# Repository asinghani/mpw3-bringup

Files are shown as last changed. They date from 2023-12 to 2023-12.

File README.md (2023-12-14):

# MPW3 Bringup / Characterization

Experiments in bringing up SKY130 MPW-3 chips from the initial tapeout in November 2021. Similarly to [MPW-1](https://github.com/asinghani/mpw1-bringup), the standardized "Caravel" padframe used in this tapeout had hold-time violations between 

## Breakout PCBs

- Characterization PCB [Schematic](boards/mpw3-common/schematic.pdf)
    - Independent voltage regulators for padframe and core (with non-volatile memory)
    - DS1077LU-50 clock generator with 50kHz - 50MHz output frequency + non-volatile memory
    - MCP23017 GPIO expanders for scanning chip I/Os
    - MCP1319 reset supervisor
    - MicroMod-style socket for Caravel chip breakout

- FTDI Breakout [Schematic](boards/uart-breakout/schematic.pdf)
    - Connects characterization PCB to FT232RL for UART access over USB
    - Includes LEDs, switches, and SPI FRAM for use with picoRF0 CPU

- VGA Breakout [Schematic](boards/vga-breakout/schematic.pdf)
    - Breaks out infinite-runner game and pong game to a 2-bit VGA DAC
    - Includes buffer chips for 

## Repo Structure

- `boards/` - KiCAD design files for breakout PCBs
- `parts/` - I/O characterization results for several dies
- `scripts/i2c_iface.py` - Script for interfacing with the voltage regulators, clock generator, and GPIO expanders on the characterization board
- `programs/` - Programs for running on the Caravel processor for the different applications
    - `aes_test.c` - Test the AES core on crypto-accelerator-chip-v2 design
    - `gpio_config_io_dino.py` - GPIO configuration for the VGA runner game
    - `gpio_config_io_pong.py` - GPIO configuration for the VGA pong game
    - `picorf0_test.c` - Test program for the picoRF0 custom CPU core
    - `read_ident.c` - Reads the ROM identifier and build number in the SHA and AES cores
    - `sha256_test.c` - Test the SHA256 core with some test vectors
    - `spi_fram.c` - Test program for using the Caravel SPI master to interface with an FRAM chip
    - `uart_working.c` - Workaround for UART RX on MPW-3 Caravel

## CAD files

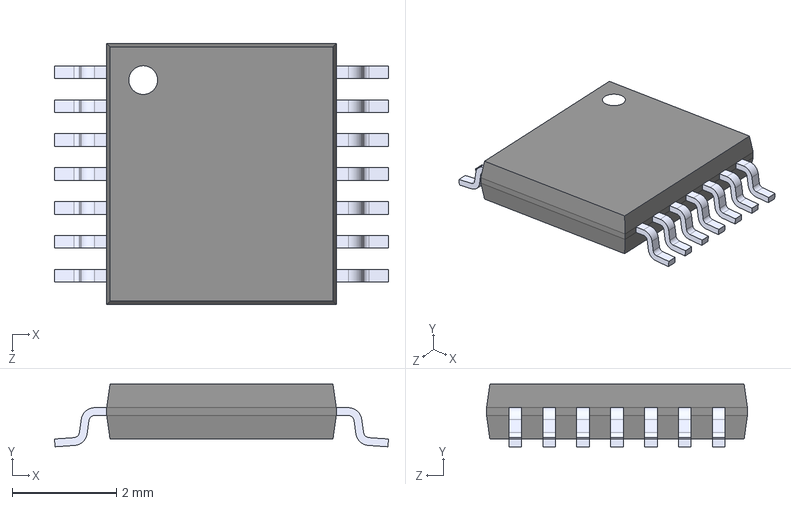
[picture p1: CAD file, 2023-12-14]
boards/mpw3-common/parts/TPL0102/TPL0102-100QPWREP.step
6.40 x 1.20 x 5.00 mm

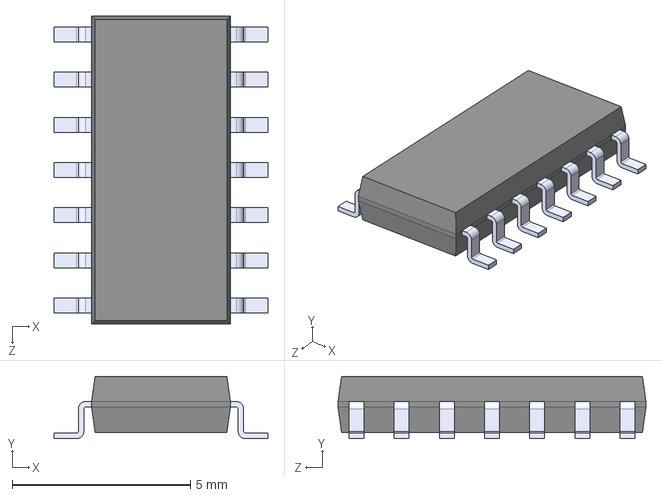
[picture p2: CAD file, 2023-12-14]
boards/uart-breakout/parts/SN74LVC32ADR/SN74LVC32ADR.step
6.00 x 1.75 x 8.65 mm

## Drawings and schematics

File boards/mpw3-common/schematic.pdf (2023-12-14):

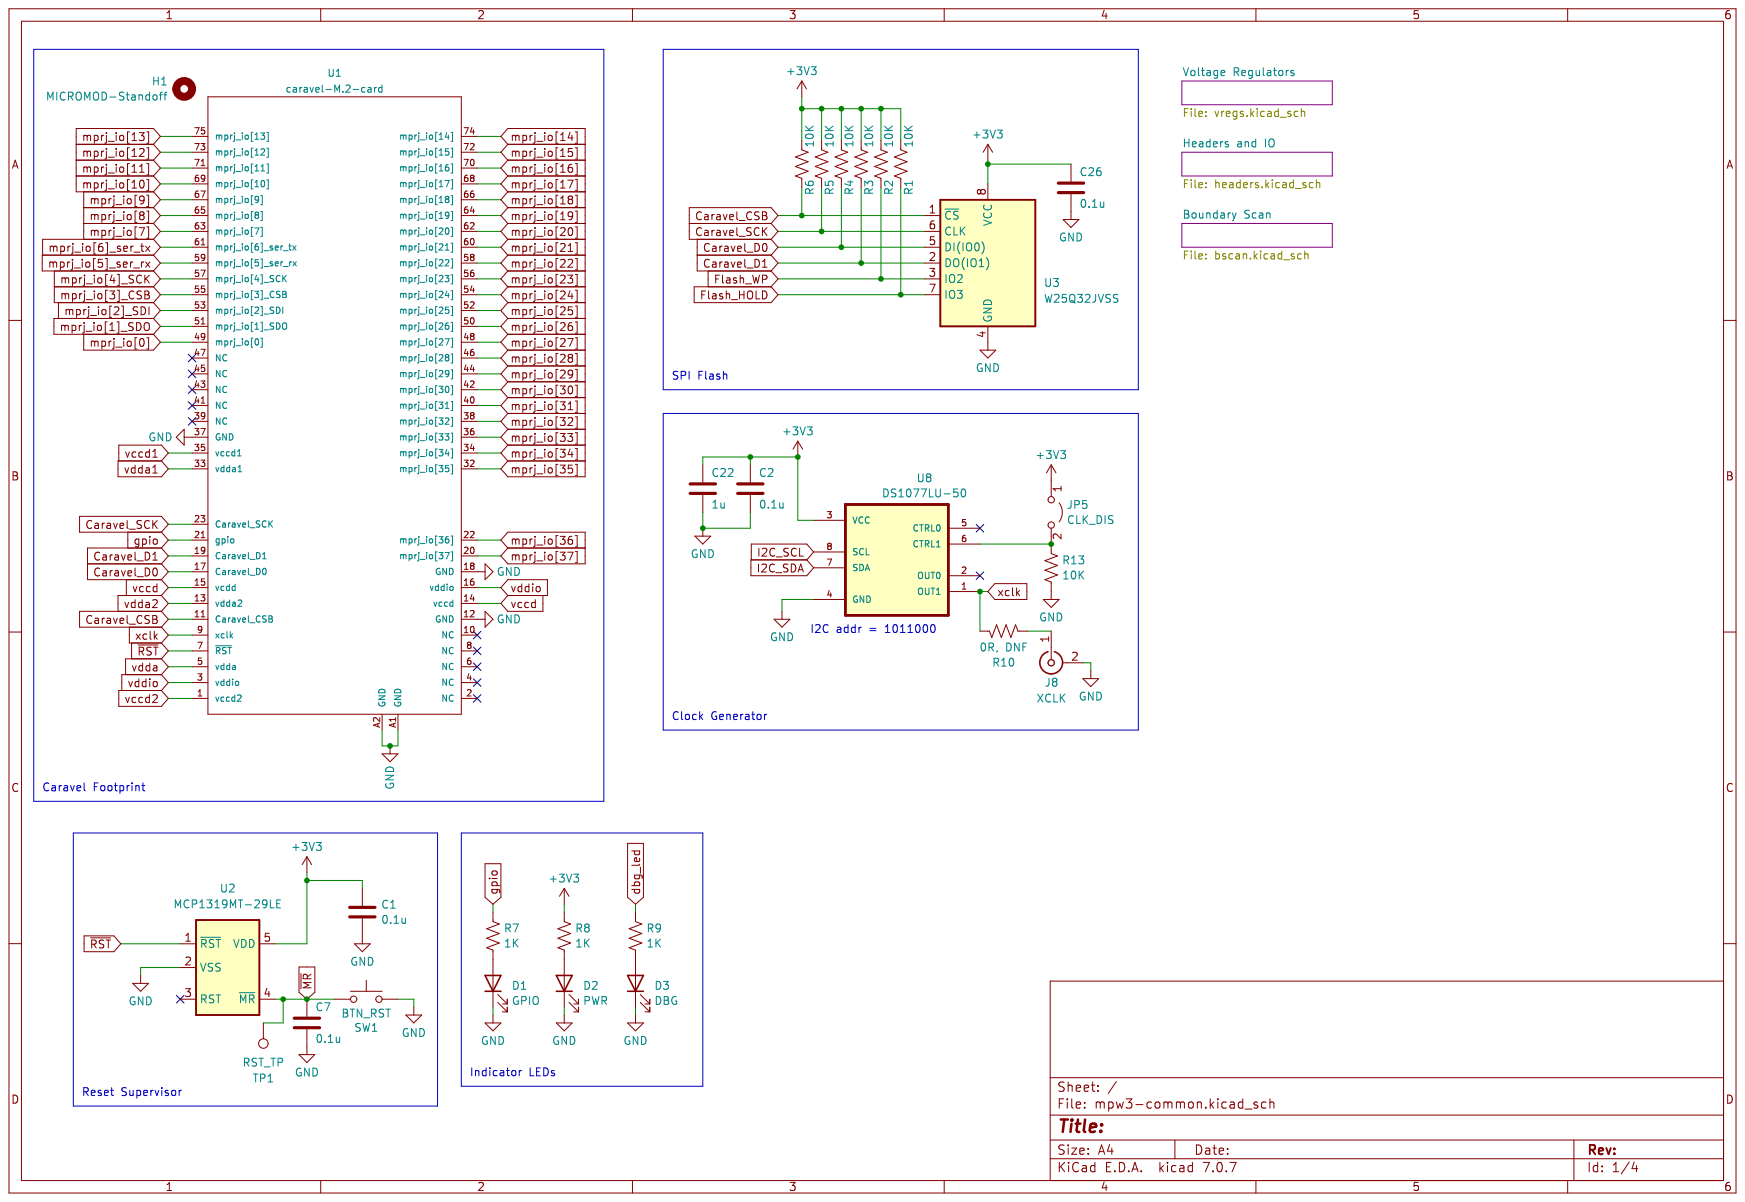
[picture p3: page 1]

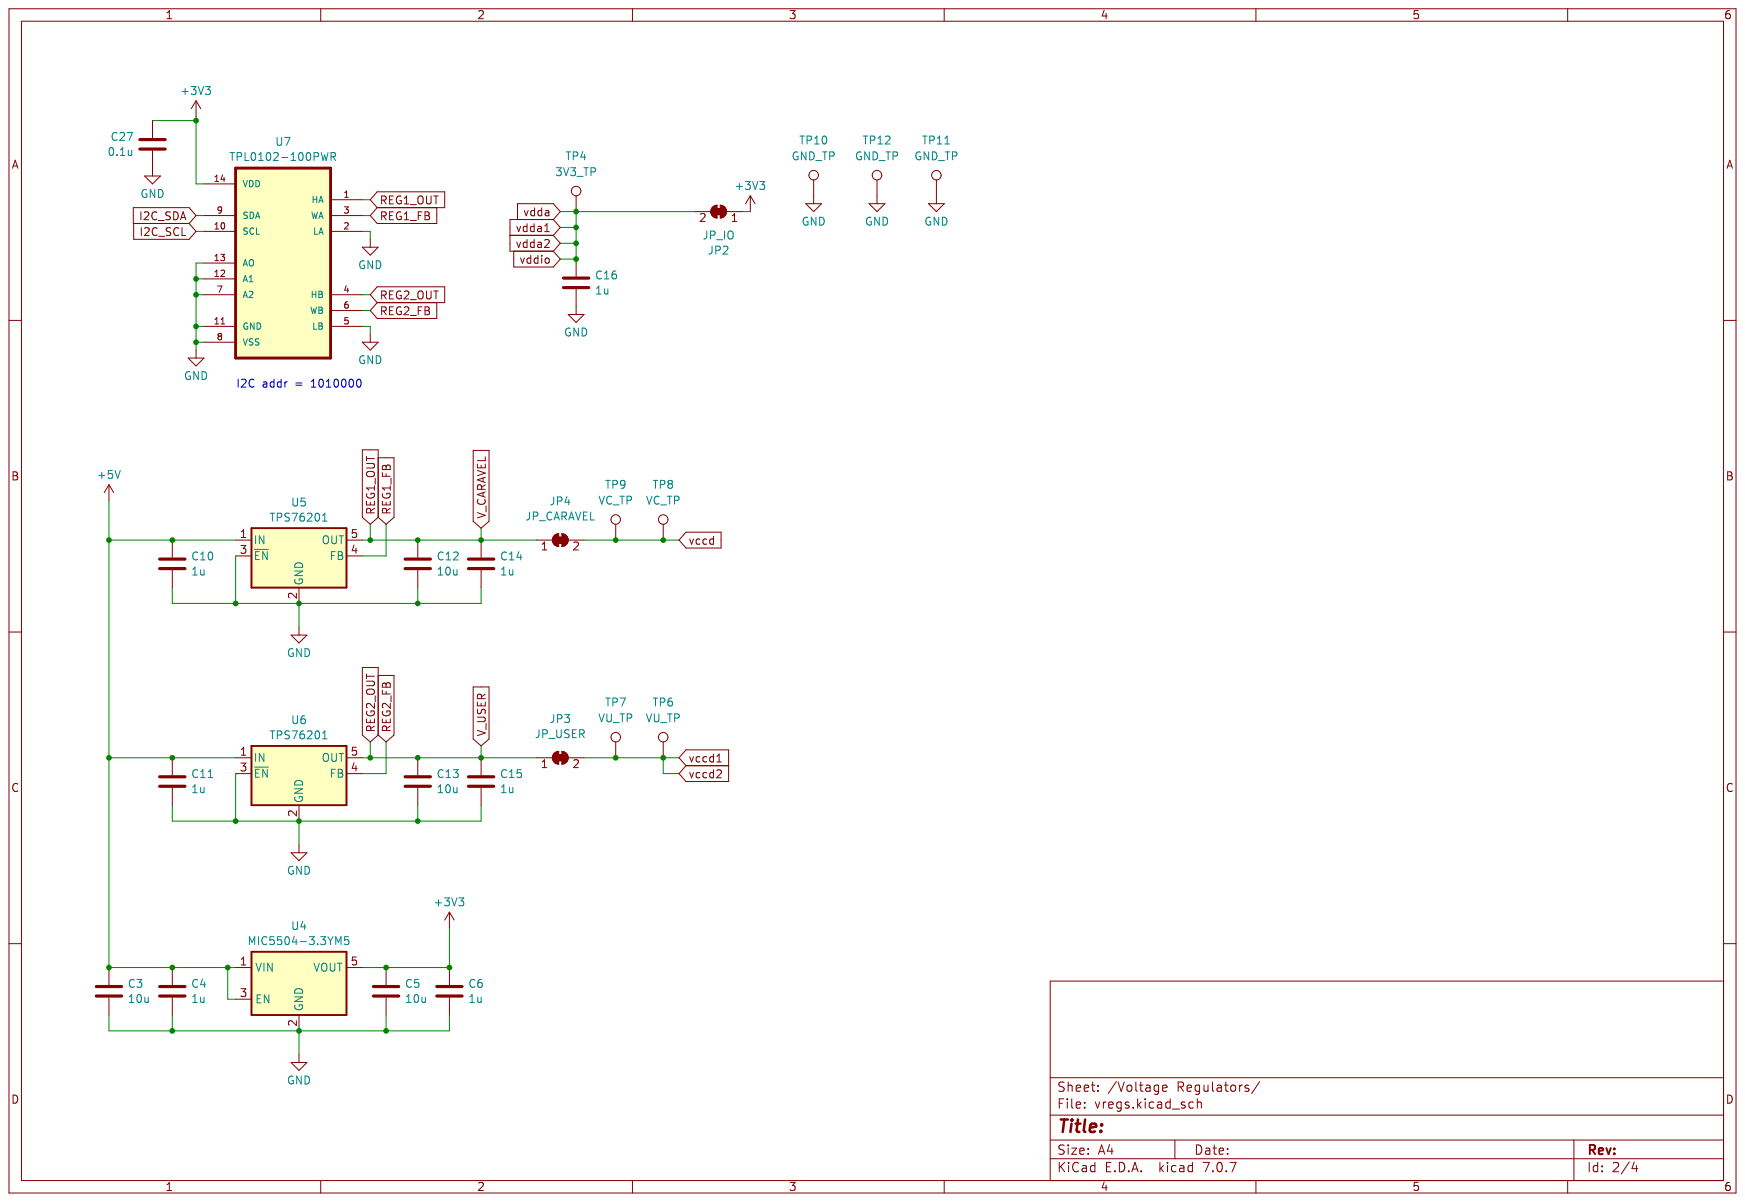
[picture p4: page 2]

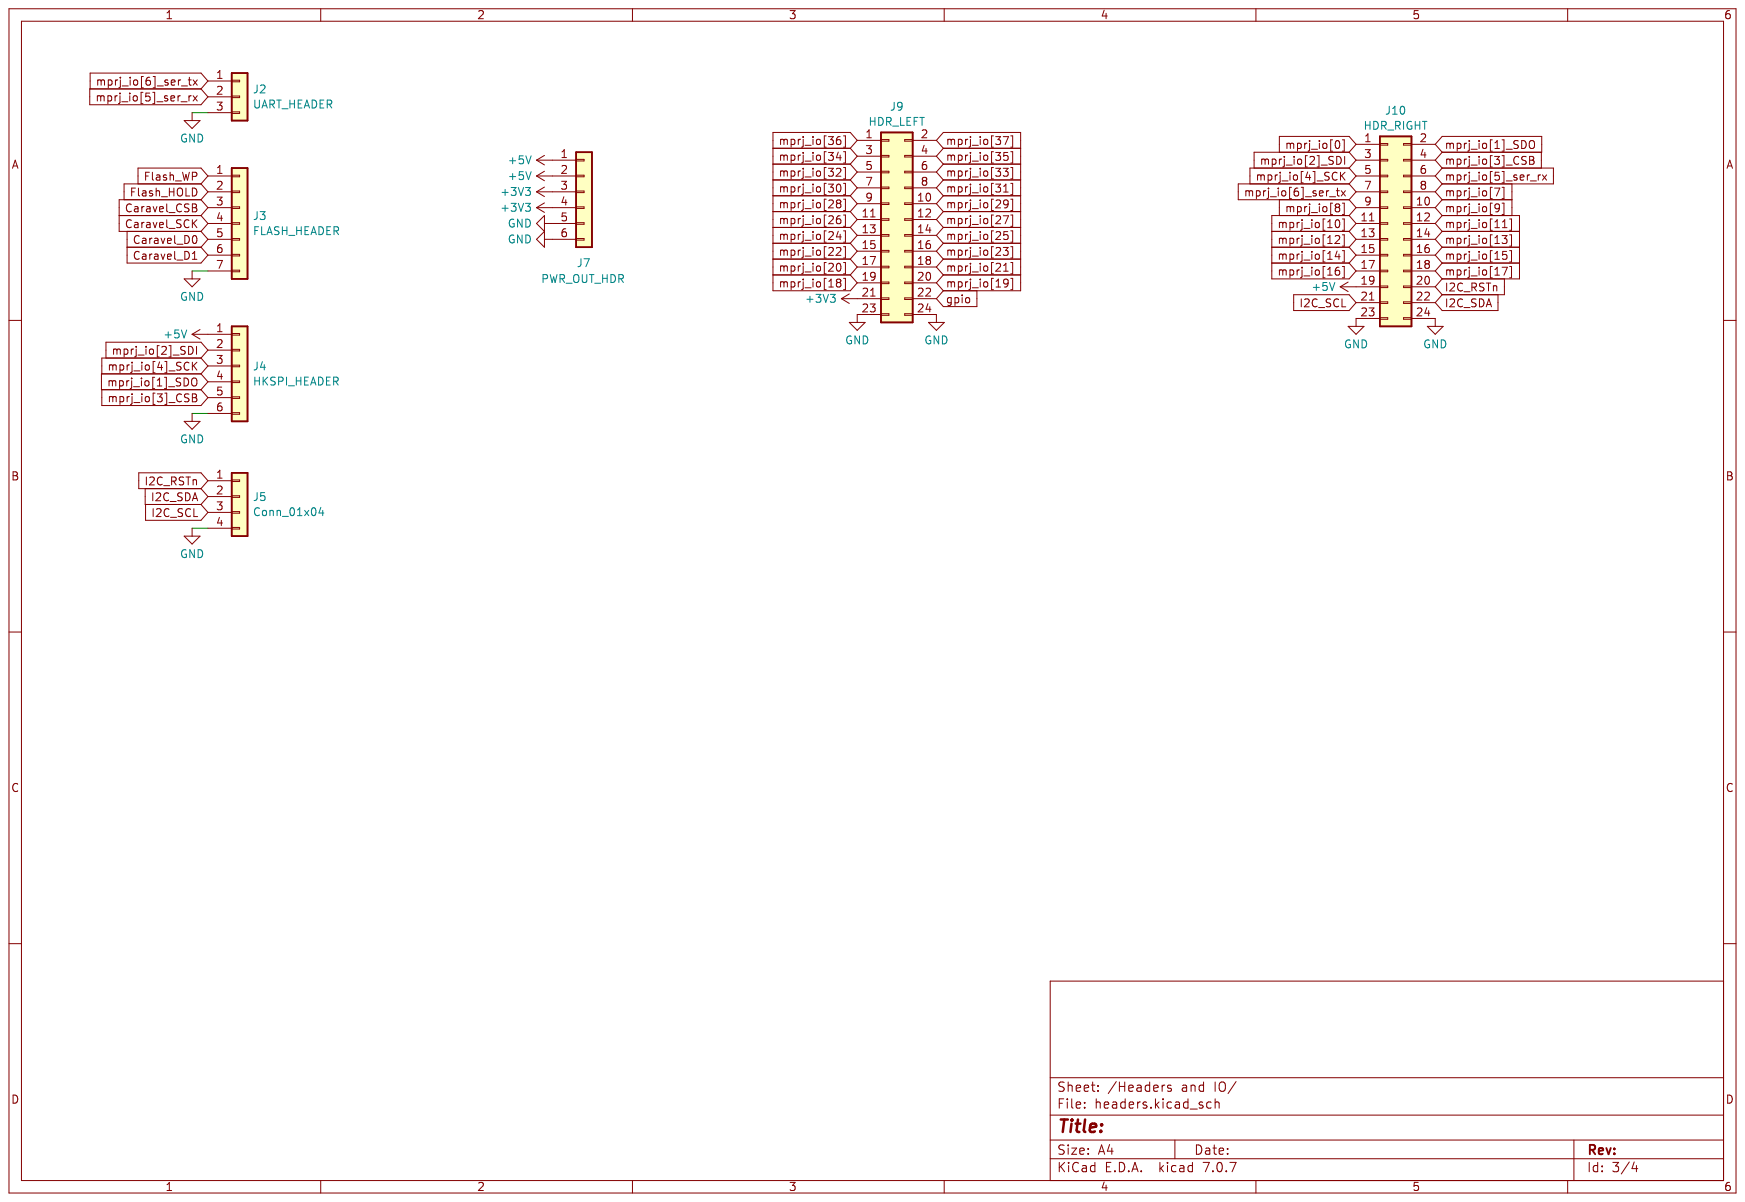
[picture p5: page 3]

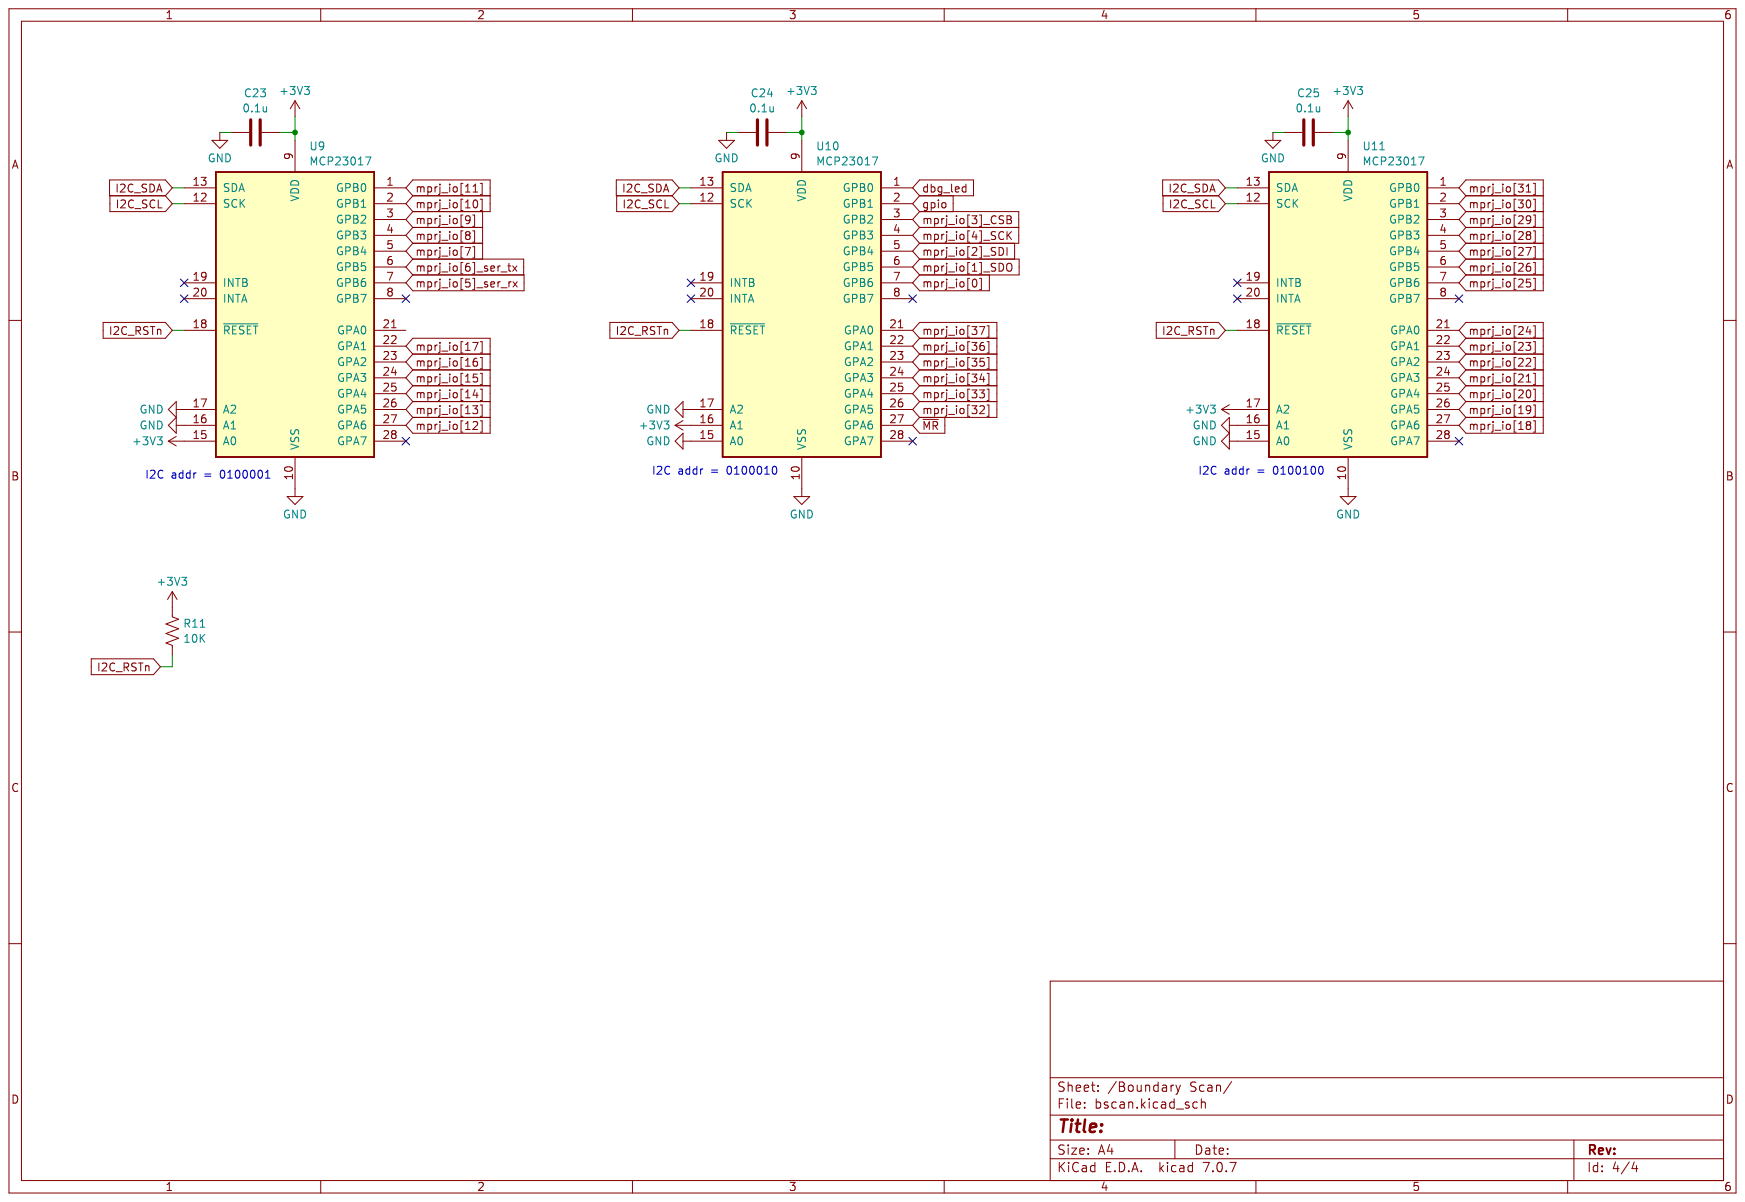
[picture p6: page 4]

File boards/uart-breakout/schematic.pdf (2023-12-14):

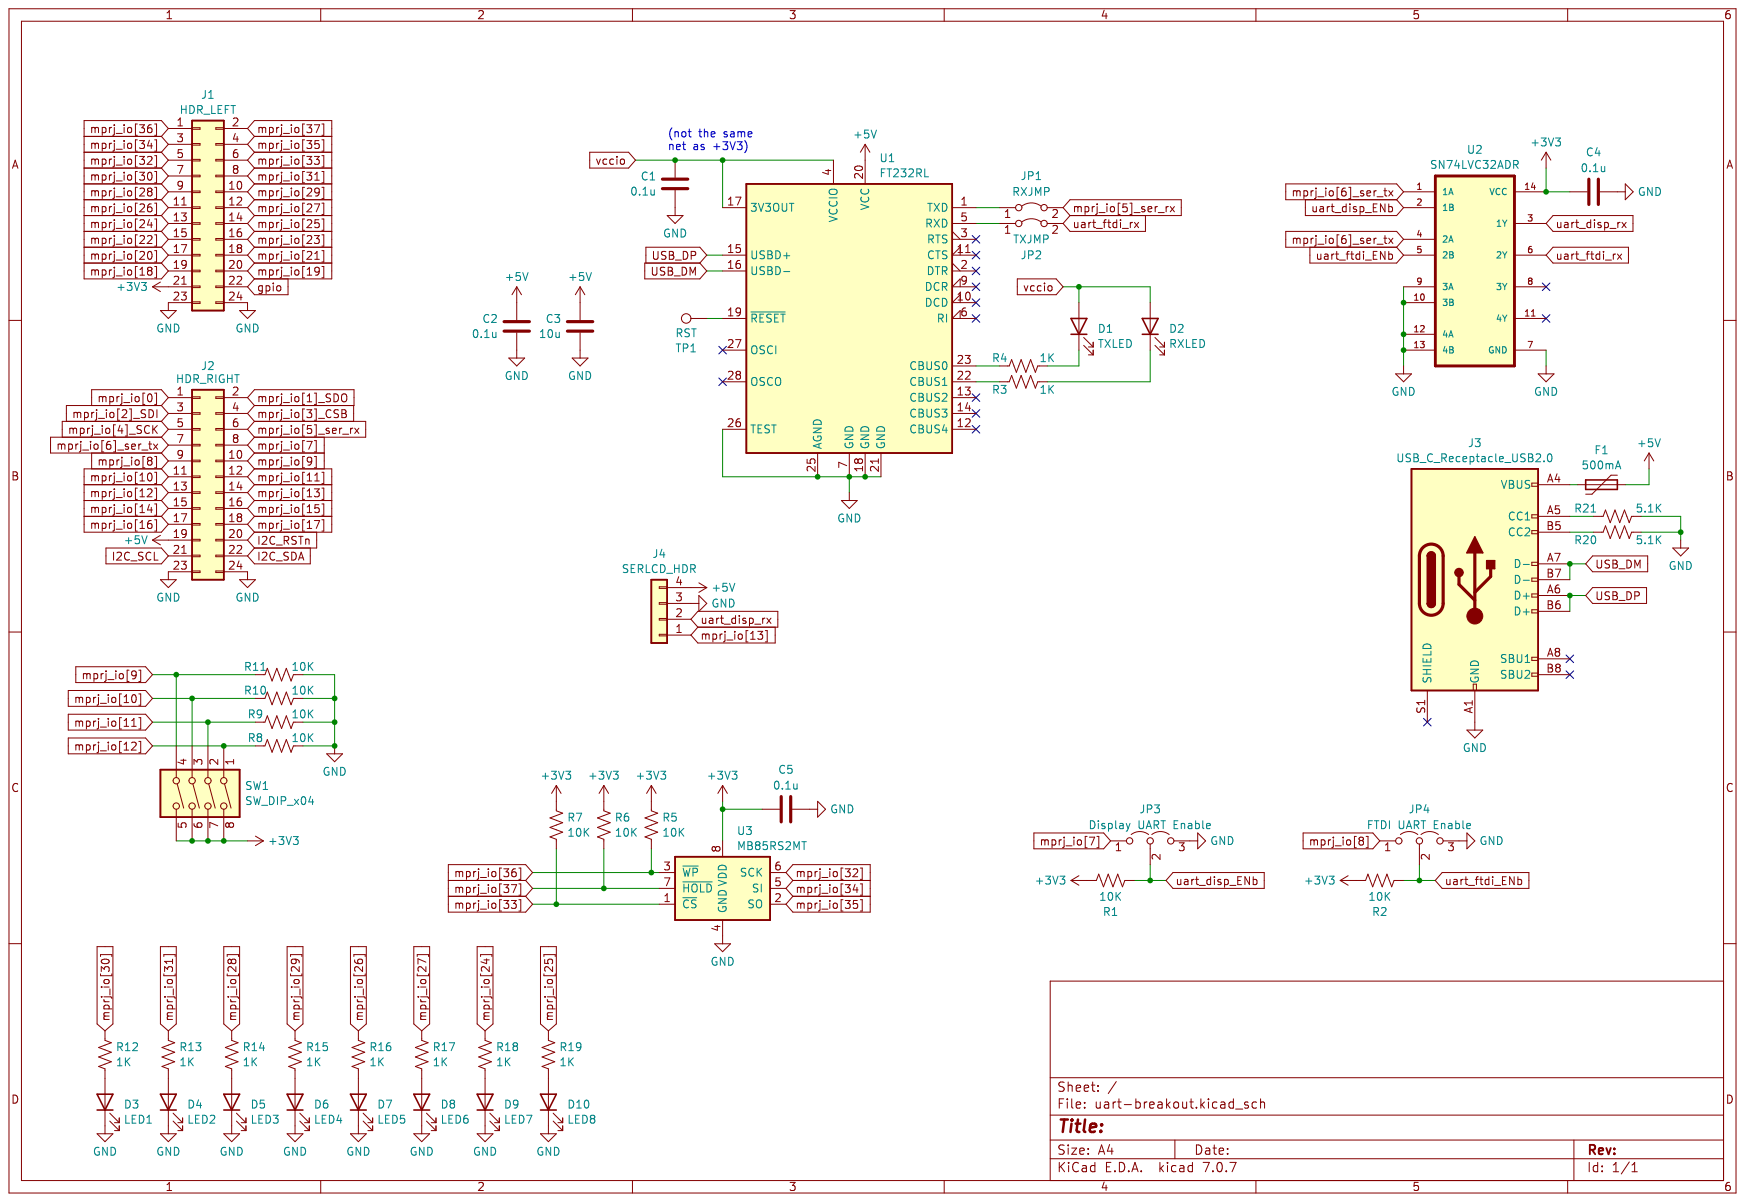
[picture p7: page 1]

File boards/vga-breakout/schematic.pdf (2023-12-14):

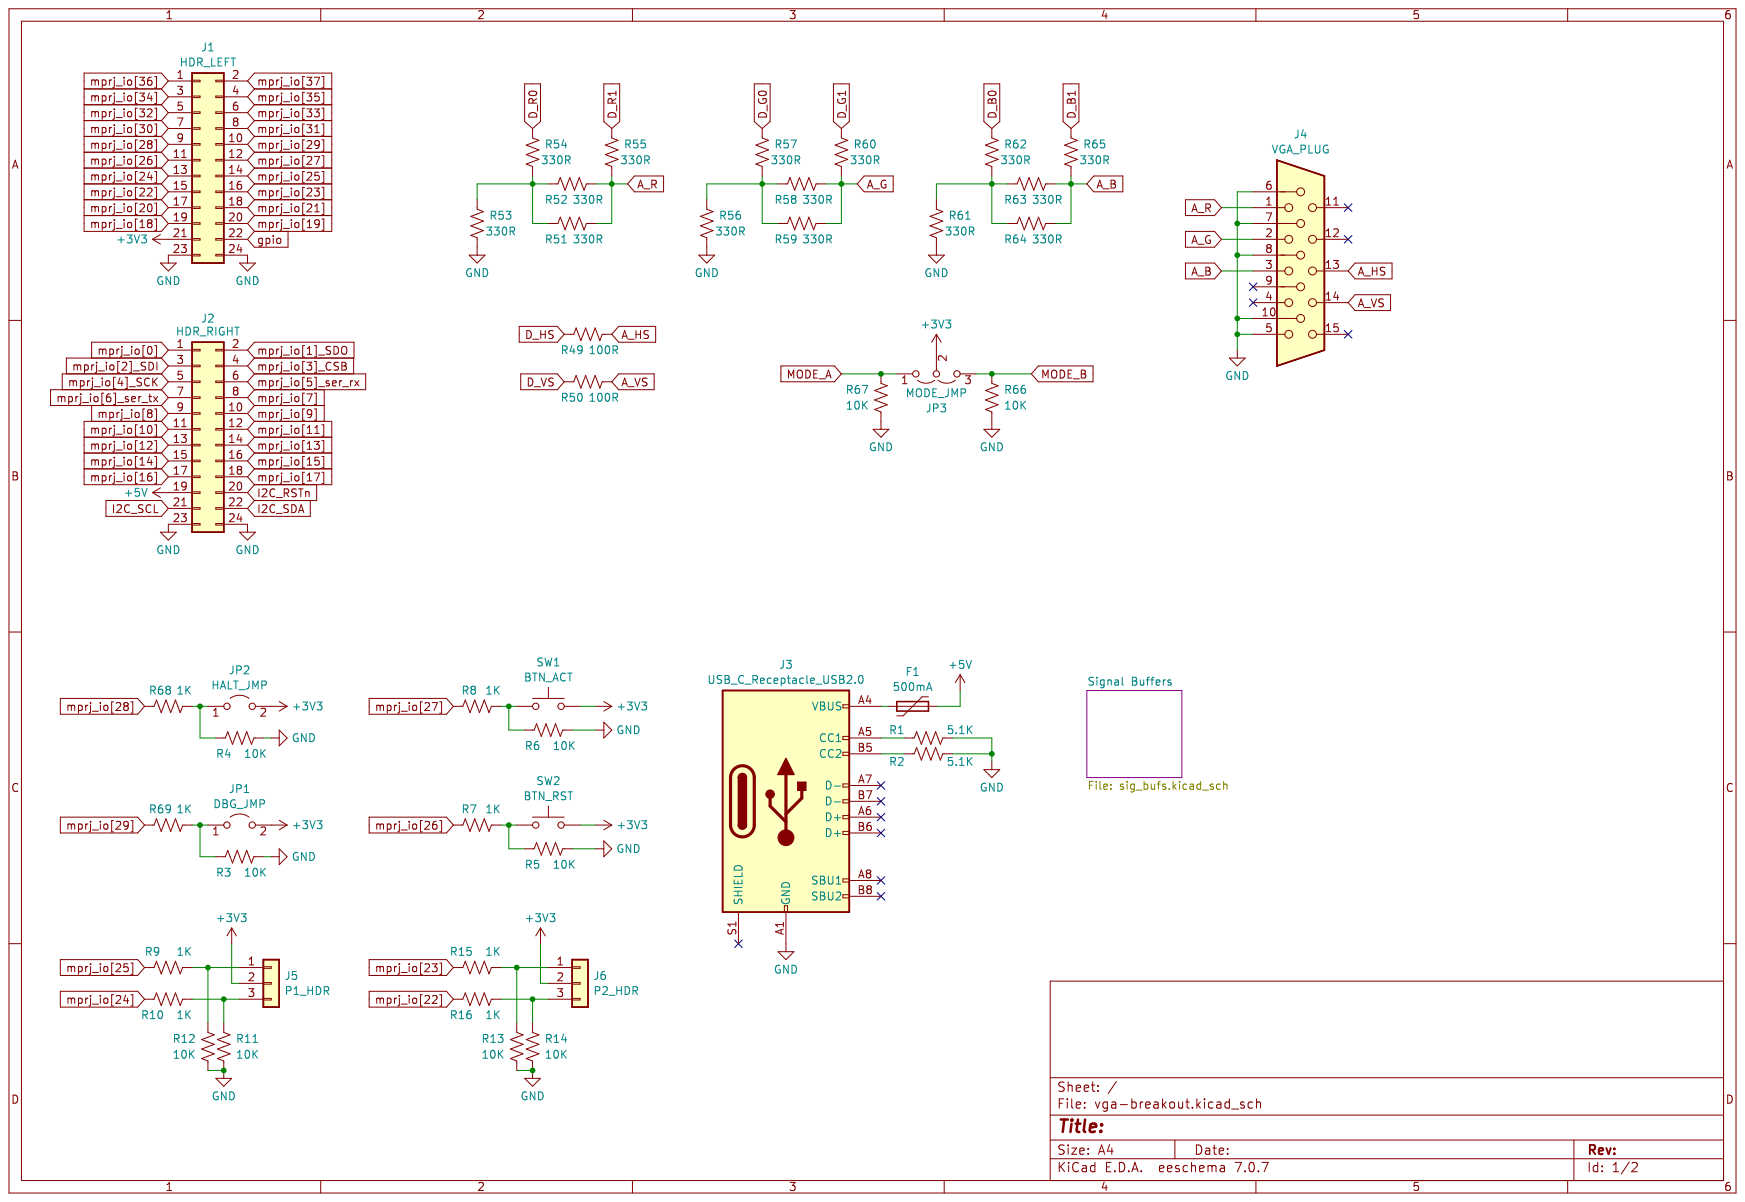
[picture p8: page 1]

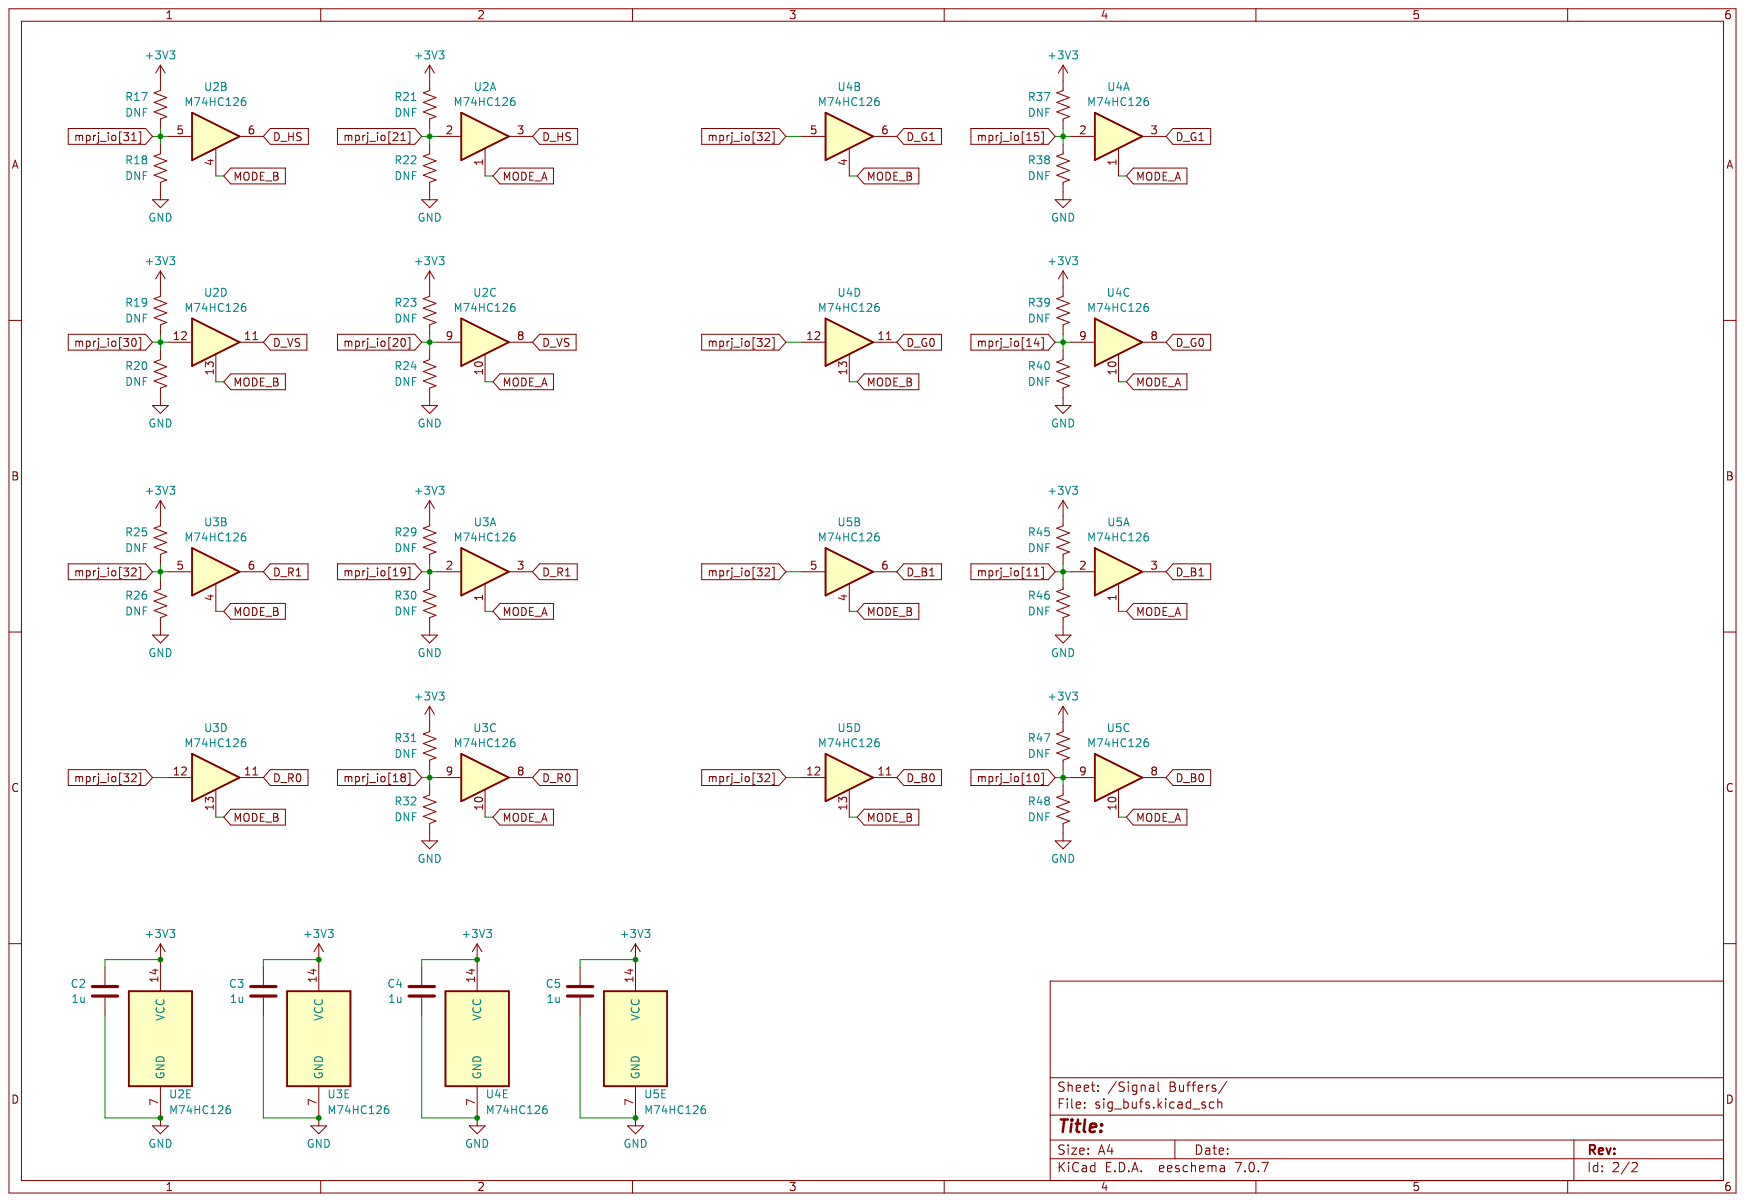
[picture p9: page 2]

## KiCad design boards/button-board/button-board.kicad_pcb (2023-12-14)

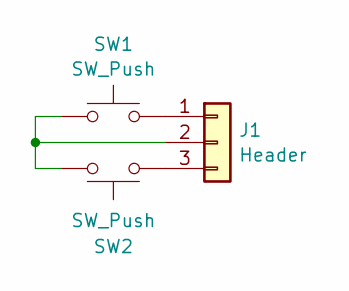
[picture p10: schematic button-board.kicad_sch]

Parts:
J1: Header; PinHeader_1x03_P2.54mm_Horizontal
SW1, SW2: SW_Push; SW_Cherry_MX_1.00u_PCB

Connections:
unnamed: J1.1, SW1.2
unnamed: J1.2, SW1.1, SW2.2
unnamed: J1.3, SW2.1

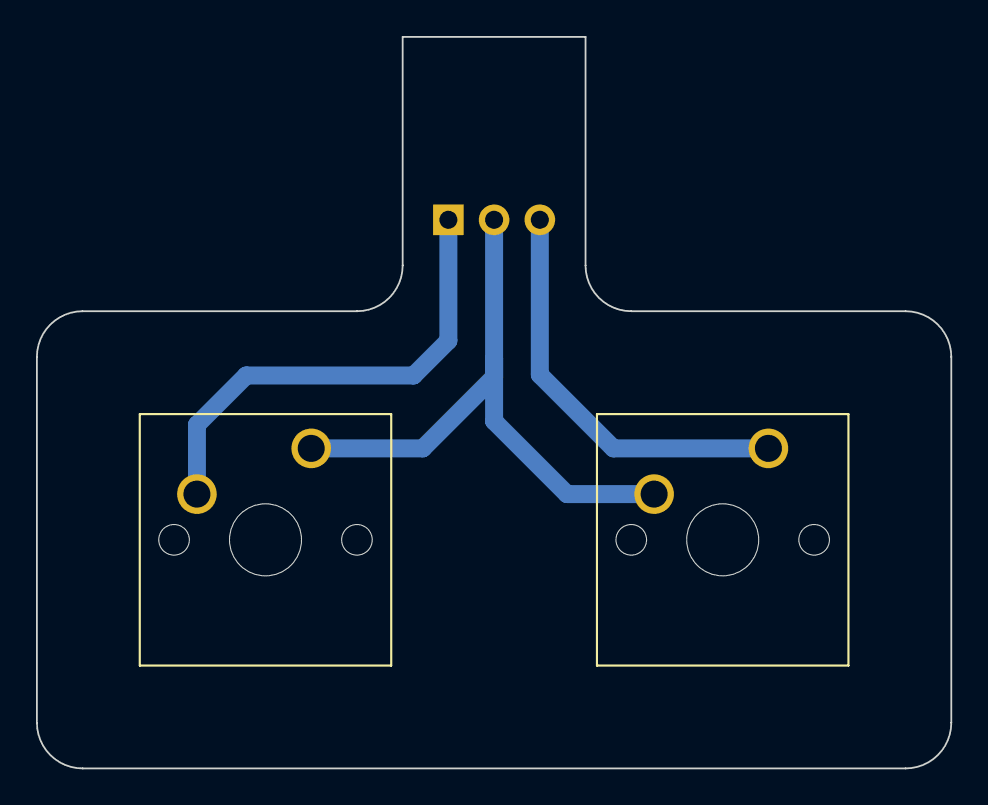
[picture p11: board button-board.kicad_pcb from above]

Board: 2 copper layers, 50.8 x 40.6 mm, 3 parts (0 on the bottom side), 3 nets.

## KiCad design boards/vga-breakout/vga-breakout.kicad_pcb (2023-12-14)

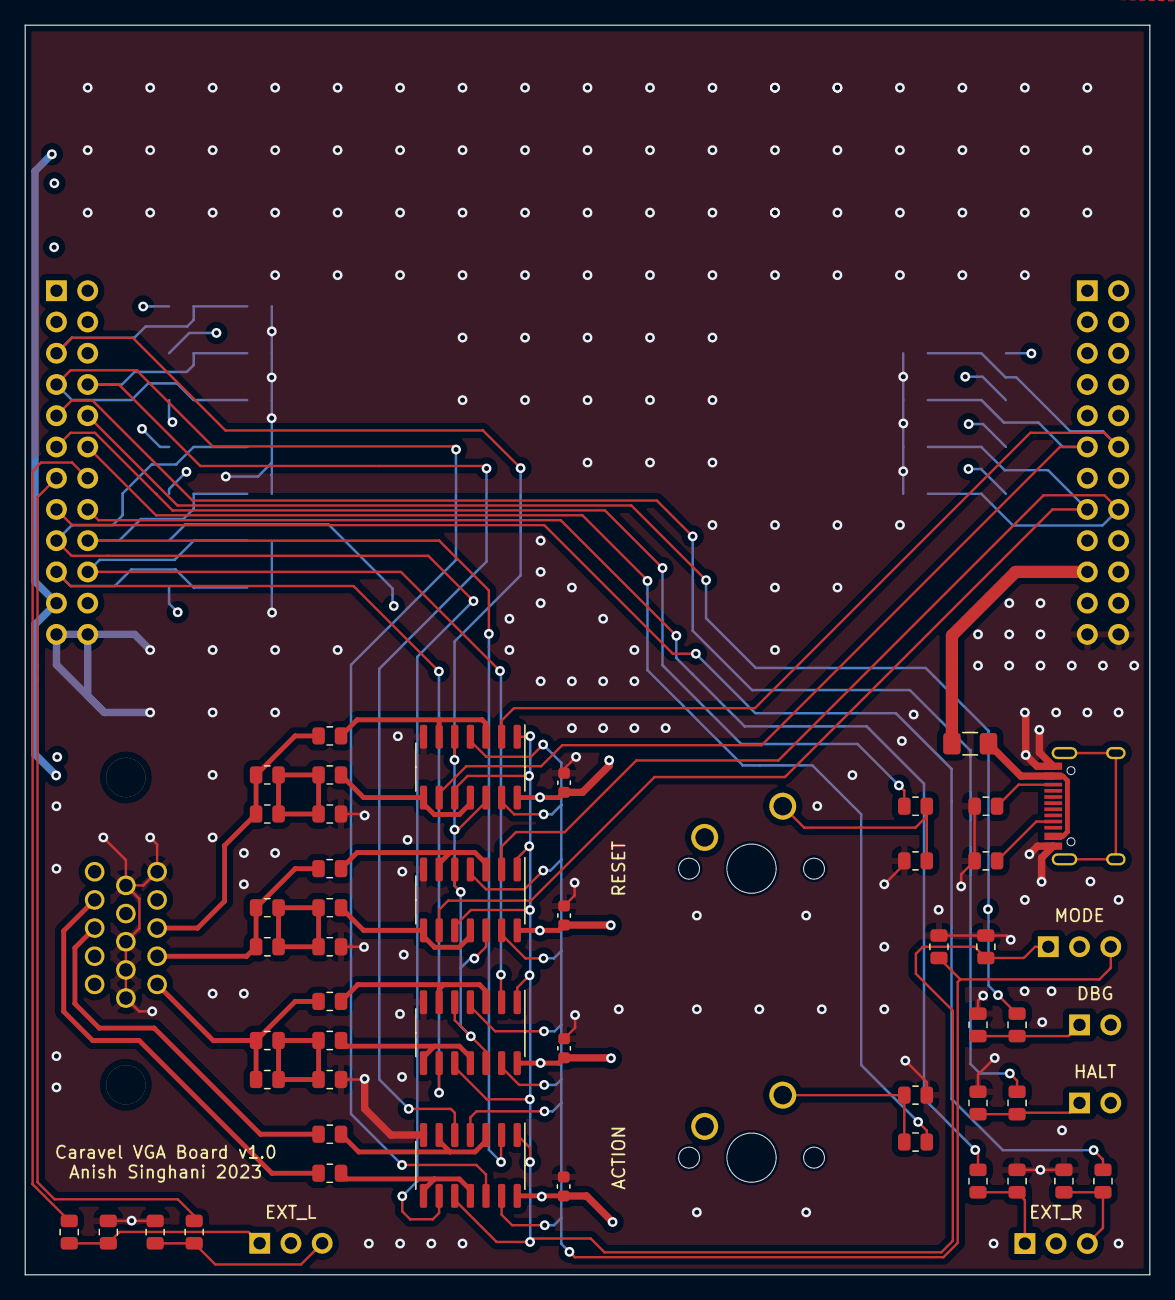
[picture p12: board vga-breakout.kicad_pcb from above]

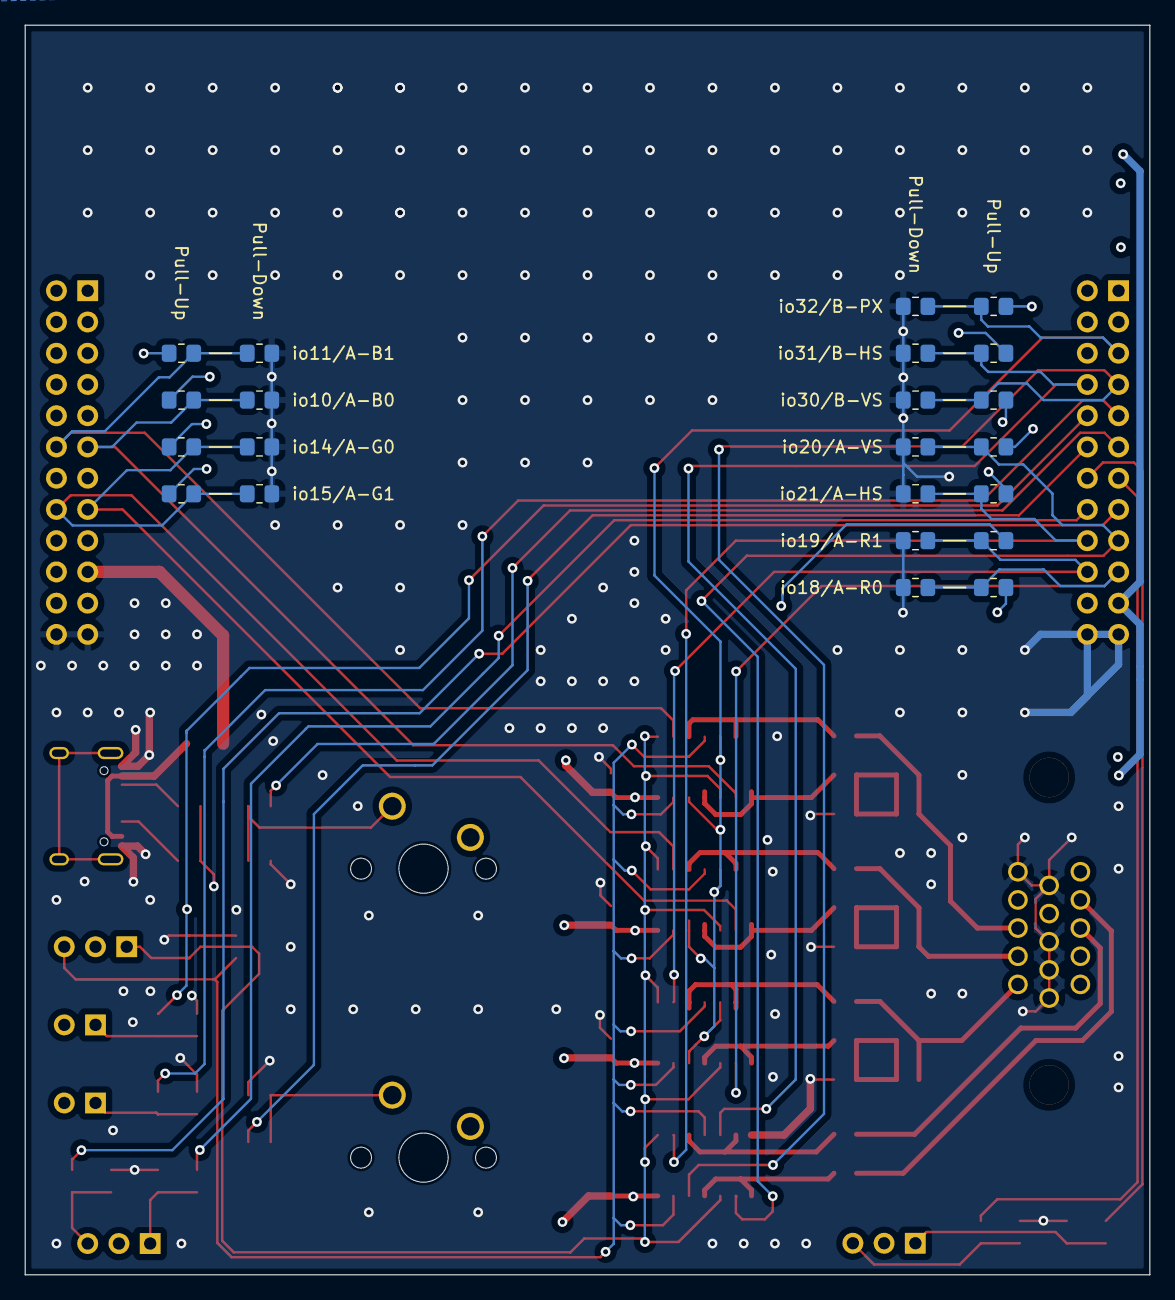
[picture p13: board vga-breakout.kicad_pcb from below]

Board: 4 copper layers, 91.4 x 101.6 mm, 79 parts (22 on the bottom side), 51 nets.

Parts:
C2, C3, C4, C5: 1u; C_0603_1608Metric
F1: 500mA; Fuse_1206_3216Metric_Pad1.42x1.75mm_HandSolder
J1: HDR_LEFT; PinHeader_2x12_P2.54mm_Vertical
J2: HDR_RIGHT; PinHeader_2x12_P2.54mm_Vertical
J3: USB_C_Receptacle_USB2.0; USB_C_Receptacle_HRO_TYPE-C-31-M-12
J4: VGA_PLUG; CONN_L77HDE15SD1CH4FVGA_AMP
J5: P1_HDR; PinSocket_1x03_P2.54mm_Vertical
J6: P2_HDR; PinSocket_1x03_P2.54mm_Vertical
JP1: DBG_JMP; PinSocket_1x02_P2.54mm_Vertical
JP2: HALT_JMP; PinSocket_1x02_P2.54mm_Vertical
JP3: MODE_JMP; PinSocket_1x03_P2.54mm_Vertical
R1, R2: 5.1K; R_0805_2012Metric
R3, R4, R5, R6, R11, R12, R13, R14, R66, R67: 10K; R_0805_2012Metric
R7, R8, R9, R10, R15, R16, R68, R69: 1K; R_0805_2012Metric
R17, R18, R19, R20, R21, R22, R23, R24, R25, R26, R29, R30, R31, R32, R37, R38, R39, R40, R45, R46, R47, R48: DNF; R_0805_2012Metric_Pad1.20x1.40mm_HandSolder
R49, R50: 100R; R_0805_2012Metric
R51, R52, R53, R54, R55, R56, R57, R58, R59, R60, R61, R62, R63, R64, R65: 330R; R_0805_2012Metric
SW1: BTN_ACT; SW_Cherry_MX_1.00u_PCB
SW2: BTN_RST; SW_Cherry_MX_1.00u_PCB
U2, U3, U4, U5: M74HC126; SO-14_3.9x8.65mm_P1.27mm

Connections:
+3V3: C2.1, C3.1, C4.1, C5.1, J1.21, J5.2, J6.2, JP1.2 (B), JP2.2 (B), JP3.2 (C), R17.2, R19.2, R21.2, R23.2, R25.2, R29.2, R31.2, R37.2, R39.2, R45.2, R47.2, SW1.2, SW2.2, U2.14 (VCC), U3.14 (VCC), U4.14 (VCC), U5.14 (VCC)
+5V: F1.1, J2.19
A_B: J4.3, R63.2, R64.2, R65.1
A_G: J4.2, R58.2, R59.2, R60.1
A_HS: J4.13, R49.2
A_R: J4.1, R51.2, R52.2, R55.1
A_VS: J4.14, R50.2
D_B0: R62.2, U5.8, U5.11
D_B1: R65.2, U5.3, U5.6
D_G0: R57.2, U4.8, U4.11
D_G1: R60.2, U4.3, U4.6
D_HS: R49.1, U2.3, U2.6
D_R0: R54.2, U3.8, U3.11
D_R1: R55.2, U3.3, U3.6
D_VS: R50.1, U2.8, U2.11
GND: C2.2, C3.2, C4.2, C5.2, J1.23, J1.24, J2.23, J2.24, J3.A1 (GND), J3.A12 (GND), J3.B1 (GND), J3.B12 (GND), J4.5, J4.6, J4.7, J4.8, J4.10, R1.1, R2.1, R3.1, R4.1, R5.1, R6.1, R11.1, R12.1, R13.1, R14.1, R18.1, R20.1, R22.1, R24.1, R26.1, R30.1, R32.1, R38.1, R40.1, R46.1, R48.1, R53.1, R56.1, R61.1, R66.1, R67.1, U2.7 (GND), U3.7 (GND), U4.7 (GND), U5.7 (GND)
MODE_A: JP3.1 (A), R67.2, U2.1, U2.10, U3.1, U3.10, U4.1, U4.10, U5.1, U5.10
MODE_B: JP3.3 (B), R66.2, U2.4, U2.13, U3.4, U3.13, U4.4, U4.13, U5.4, U5.13
unnamed: F1.2, J3.A4 (VBUS), J3.A9 (VBUS), J3.B4 (VBUS), J3.B9 (VBUS)
unnamed: J3.A5 (CC1), R1.2
unnamed: J3.B5 (CC2), R2.2
unnamed: J5.1, R9.2, R12.2
unnamed: J5.3, R10.2, R11.2
unnamed: J6.1, R13.2, R15.2
unnamed: J6.3, R14.2, R16.2
unnamed: JP1.1 (A), R3.2, R69.2
unnamed: JP2.1 (A), R4.2, R68.2
unnamed: R5.2, R7.2, SW2.1
unnamed: R6.2, R8.2, SW1.1
unnamed: R51.1, R52.1, R53.2, R54.1
unnamed: R56.2, R57.1, R58.1, R59.1
unnamed: R61.2, R62.1, R63.1, R64.1
mprj_io[10]: J2.11, R47.1, R48.2, U5.9
mprj_io[11]: J2.12, R45.1, R46.2, U5.2
mprj_io[14]: J2.15, R39.1, R40.2, U4.9
mprj_io[15]: J2.16, R37.1, R38.2, U4.2
mprj_io[18]: J1.19, R31.1, R32.2, U3.9
mprj_io[19]: J1.20, R29.1, R30.2, U3.2
mprj_io[20]: J1.17, R23.1, R24.2, U2.9
mprj_io[21]: J1.18, R21.1, R22.2, U2.2
mprj_io[22]: J1.15, R16.1
mprj_io[23]: J1.16, R15.1
mprj_io[24]: J1.13, R10.1
mprj_io[25]: J1.14, R9.1
mprj_io[26]: J1.11, R7.1
mprj_io[27]: J1.12, R8.1
mprj_io[28]: J1.9, R68.1
mprj_io[29]: J1.10, R69.1
mprj_io[30]: J1.7, R19.1, R20.2, U2.12
mprj_io[31]: J1.8, R17.1, R18.2, U2.5
mprj_io[32]: J1.5, R25.1, R26.2, U3.5, U3.12, U4.5, U4.12, U5.5, U5.12

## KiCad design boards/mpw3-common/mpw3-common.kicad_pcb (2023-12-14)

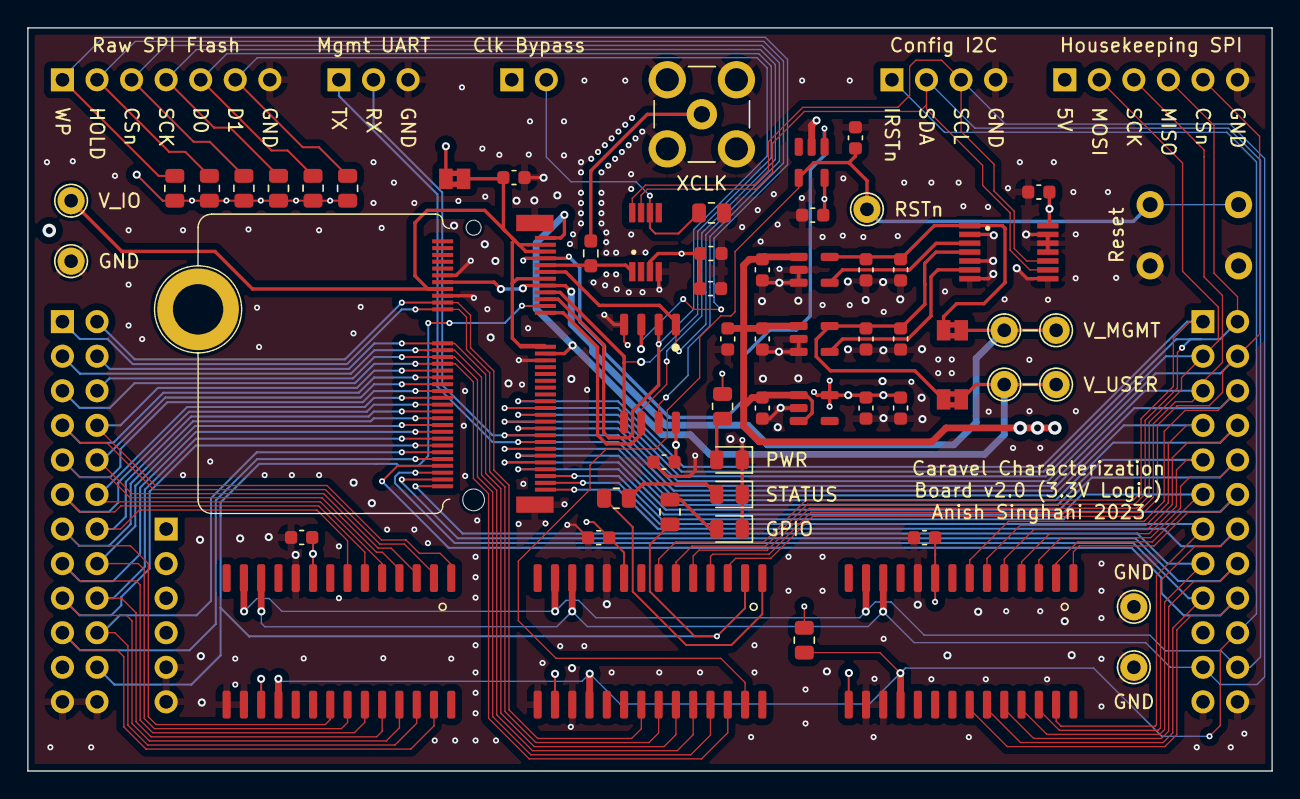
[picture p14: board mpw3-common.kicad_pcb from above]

Board: 4 copper layers, 91.4 x 54.6 mm, 69 parts (0 on the bottom side), 67 nets.

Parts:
C1, C2, C7, C23, C24, C25, C26, C27: 0.1u; C_0603_1608Metric
C3, C5, C12, C13: 10u; C_0603_1608Metric
C4, C6, C10, C11, C14, C15, C16, C22: 1u; C_0603_1608Metric
D1: GPIO; LED_0805_2012Metric
D2: PWR; LED_0805_2012Metric
D3: DBG; LED_0805_2012Metric
H1: MICROMOD-Standoff; MicroMod-Standoff
J2: UART_HEADER; PinHeader_1x03_P2.54mm_Vertical
J3: FLASH_HEADER; PinHeader_1x07_P2.54mm_Vertical
J4: HKSPI_HEADER; PinHeader_1x06_P2.54mm_Vertical
J5: Conn_01x04; PinHeader_1x04_P2.54mm_Vertical
J7: PWR_OUT_HDR; PinHeader_1x06_P2.54mm_Vertical
J8: XCLK; SMB_Jack_Vertical
J9: HDR_LEFT; PinHeader_2x12_P2.54mm_Vertical
J10: HDR_RIGHT; PinHeader_2x12_P2.54mm_Vertical
JP2: JP_IO; SolderJumper-2_P1.3mm_Bridged2Bar_Pad1.0x1.5mm
JP3: JP_USER; SolderJumper-2_P1.3mm_Bridged2Bar_Pad1.0x1.5mm
JP4: JP_CARAVEL; SolderJumper-2_P1.3mm_Bridged2Bar_Pad1.0x1.5mm
JP5: CLK_DIS; PinHeader_1x02_P2.54mm_Vertical
R1, R2, R3, R4, R5, R6, R11, R13: 10K; R_0805_2012Metric
R7, R8, R9: 1K; R_0805_2012Metric
R10: 0R, DNF; R_0603_1608Metric_Pad0.98x0.95mm_HandSolder
SW1: BTN_RST; SW_PUSH_6mm
TP1: RST_TP; TestPoint_THTPad_D2.0mm_Drill1.0mm
TP4: 3V3_TP; TestPoint_THTPad_D2.0mm_Drill1.0mm
TP6, TP7: VU_TP; TestPoint_THTPad_D2.0mm_Drill1.0mm
TP8, TP9: VC_TP; TestPoint_THTPad_D2.0mm_Drill1.0mm
TP10, TP11, TP12: GND_TP; TestPoint_THTPad_D2.0mm_Drill1.0mm
U1: caravel-M.2-card; M.2-CONNECTOR-E
U2: MCP1319MT-29LE; SOT-23-5
U3: W25Q32JVSS; SOIC-8_5.23x5.23mm_P1.27mm
U4: MIC5504-3.3YM5; SOT-23-5
U5, U6: TPS76201; SOT-23-5
U7: TPL0102-100PWR; SOP65P640X120-14N
U8: DS1077LU-50; SOP65P490X110-8N
U9, U10, U11: MCP23017; SOIC-28W_7.5x17.9mm_P1.27mm

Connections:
+3V3: C1.1, C2.1, C5.2, C6.2, C22.1, C23.1, C24.1, C25.1, C26.1, C27.1, J7.3, J7.4, J9.21, JP2.1 (A), JP5.1 (A), R1.1, R2.1, R3.1, R4.1, R5.1, R6.1, R8.1, R11.1, U2.5 (VDD), U3.8 (VCC), U4.5 (VOUT), U7.14 (VDD), U8.3 (VCC), U9.9 (VDD), U9.15 (A0), U10.9 (VDD), U10.16 (A1), U11.9 (VDD), U11.17 (A2)
+5V: C3.2, C4.2, C10.2, C11.2, J4.1, J7.1, J7.2, J10.19, U4.1 (VIN), U4.3 (EN), U5.1 (IN), U6.1 (IN)
Caravel_CSB: J3.3, R6.2, U1.11 (Caravel_CSB), U3.1 (~CS)
Caravel_D0: J3.5, R4.2, U1.17 (Caravel_D0), U3.5 (DI(IO0))
Caravel_D1: J3.6, R3.2, U1.19 (Caravel_D1), U3.2 (DO(IO1))
Caravel_SCK: J3.4, R5.2, U1.23 (Caravel_SCK), U3.6 (CLK)
Flash_HOLD: J3.2, R1.2, U3.7 (IO3)
Flash_WP: J3.1, R2.2, U3.3 (IO2)
GND: C1.2, C2.2, C3.1, C4.1, C5.1, C6.1, C7.2, C10.1, C11.1, C12.1, C13.1, C14.1, C15.1, C16.2, C22.2, C23.2, C24.2, C25.2, C26.2, C27.2, D1.1 (K), D2.1 (K), D3.1 (K), J2.3, J3.7, J4.6, J5.4, J7.5, J7.6, J8.2 (Ext), J9.23, J9.24, J10.23, J10.24, R13.2, SW1.2, TP10.1, TP11.1, TP12.1, U1.12 (GND), U1.18 (GND), U1.37 (GND), U1.A1 (GND), U1.A2 (GND), U2.2 (VSS), U3.4 (GND), U4.2 (GND), U5.2 (GND), U5.3 (~EN), U6.2 (GND), U6.3 (~EN), U7.2 (LA), U7.5 (LB), U7.7 (A2), U7.8 (VSS), U7.11 (GND), U7.12 (A1), U7.13 (AO), U8.4 (GND), U9.10 (VSS), U9.16 (A1), U9.17 (A2), U10.10 (VSS), U10.15 (A0), U10.17 (A2), U11.10 (VSS), U11.15 (A0), U11.16 (A1)
I2C_RSTn: J5.1, J10.20, R11.2, U9.18 (~RESET), U10.18 (~RESET), U11.18 (~RESET)
I2C_SCL: J5.3, J10.21, U7.10 (SCL), U8.8 (SCL), U9.12 (SCK), U10.12 (SCK), U11.12 (SCK)
I2C_SDA: J5.2, J10.22, U7.9 (SDA), U8.7 (SDA), U9.13 (SDA), U10.13 (SDA), U11.13 (SDA)
unnamed: D1.2 (A), R7.2
unnamed: D2.2 (A), R8.2
unnamed: D3.2 (A), R9.2
unnamed: J8.1 (In), R10.1
unnamed: JP5.2 (B), R13.1, U8.6 (CTRL1)
REG1_FB: U5.4 (FB), U7.3 (WA)
REG1_OUT: C12.2, C14.2, JP4.1 (A), U5.5 (OUT), U7.1 (HA)
REG2_FB: U6.4 (FB), U7.6 (WB)
REG2_OUT: C13.2, C15.2, JP3.1 (A), U6.5 (OUT), U7.4 (HB)
dbg_led: R9.1, U10.1 (GPB0)
gpio: J9.22, R7.1, U1.21 (gpio), U10.2 (GPB1)
mprj_io[0]: J10.1, U1.49 (mprj_io[0]), U10.7 (GPB6)
mprj_io[1]_SDO: J4.4, J10.2, U1.51 (mprj_io[1]_SDO), U10.6 (GPB5)
mprj_io[2]_SDI: J4.2, J10.3, U1.53 (mprj_io[2]_SDI), U10.5 (GPB4)
mprj_io[3]_CSB: J4.5, J10.4, U1.55 (mprj_io[3]_CSB), U10.3 (GPB2)
mprj_io[4]_SCK: J4.3, J10.5, U1.57 (mprj_io[4]_SCK), U10.4 (GPB3)
mprj_io[5]_ser_rx: J2.2, J10.6, U1.59 (mprj_io[5]_ser_rx), U9.7 (GPB6)
mprj_io[6]_ser_tx: J2.1, J10.7, U1.61 (mprj_io[6]_ser_tx), U9.6 (GPB5)
mprj_io[7]: J10.8, U1.63 (mprj_io[7]), U9.5 (GPB4)
mprj_io[8]: J10.9, U1.65 (mprj_io[8]), U9.4 (GPB3)
mprj_io[9]: J10.10, U1.67 (mprj_io[9]), U9.3 (GPB2)
mprj_io[10]: J10.11, U1.69 (mprj_io[10]), U9.2 (GPB1)
mprj_io[11]: J10.12, U1.71 (mprj_io[11]), U9.1 (GPB0)
mprj_io[12]: J10.13, U1.73 (mprj_io[12]), U9.27 (GPA6)
mprj_io[13]: J10.14, U1.75 (mprj_io[13]), U9.26 (GPA5)
mprj_io[14]: J10.15, U1.74 (mprj_io[14]), U9.25 (GPA4)
mprj_io[15]: J10.16, U1.72 (mprj_io[15]), U9.24 (GPA3)
mprj_io[16]: J10.17, U1.70 (mprj_io[16]), U9.23 (GPA2)
mprj_io[17]: J10.18, U1.68 (mprj_io[17]), U9.22 (GPA1)
mprj_io[18]: J9.19, U1.66 (mprj_io[18]), U11.27 (GPA6)
mprj_io[19]: J9.20, U1.64 (mprj_io[19]), U11.26 (GPA5)
mprj_io[20]: J9.17, U1.62 (mprj_io[20]), U11.25 (GPA4)
mprj_io[21]: J9.18, U1.60 (mprj_io[21]), U11.24 (GPA3)
mprj_io[22]: J9.15, U1.58 (mprj_io[22]), U11.23 (GPA2)
mprj_io[23]: J9.16, U1.56 (mprj_io[23]), U11.22 (GPA1)
mprj_io[24]: J9.13, U1.54 (mprj_io[24]), U11.21 (GPA0)
mprj_io[25]: J9.14, U1.52 (mprj_io[25]), U11.7 (GPB6)
mprj_io[26]: J9.11, U1.50 (mprj_io[26]), U11.6 (GPB5)
mprj_io[27]: J9.12, U1.48 (mprj_io[27]), U11.5 (GPB4)
mprj_io[28]: J9.9, U1.46 (mprj_io[28]), U11.4 (GPB3)
mprj_io[29]: J9.10, U1.44 (mprj_io[29]), U11.3 (GPB2)
mprj_io[30]: J9.7, U1.42 (mprj_io[30]), U11.2 (GPB1)
mprj_io[31]: J9.8, U1.40 (mprj_io[31]), U11.1 (GPB0)
mprj_io[32]: J9.5, U1.38 (mprj_io[32]), U10.26 (GPA5)
mprj_io[33]: J9.6, U1.36 (mprj_io[33]), U10.25 (GPA4)
mprj_io[34]: J9.3, U1.34 (mprj_io[34]), U10.24 (GPA3)
mprj_io[35]: J9.4, U1.32 (mprj_io[35]), U10.23 (GPA2)
mprj_io[36]: J9.1, U1.22 (mprj_io[36]), U10.22 (GPA1)
mprj_io[37]: J9.2, U1.20 (mprj_io[37]), U10.21 (GPA0)
vccd: JP4.2 (B), TP8.1, TP9.1, U1.14 (vccd), U1.15 (vcdd)
vccd1: JP3.2 (B), TP6.1, TP7.1, U1.1 (vccd2), U1.35 (vccd1)
vdda: C16.1, JP2.2 (B), TP4.1, U1.3 (vddio), U1.5 (vdda), U1.13 (vdda2), U1.16 (vddio), U1.33 (vdda1)
xclk: R10.2, U1.9 (xclk), U8.1 (OUT1)
~MR: C7.1, SW1.1, TP1.1, U2.4 (~MR), U10.27 (GPA6)
~RST: U1.7 (~RST), U2.1 (~RST)

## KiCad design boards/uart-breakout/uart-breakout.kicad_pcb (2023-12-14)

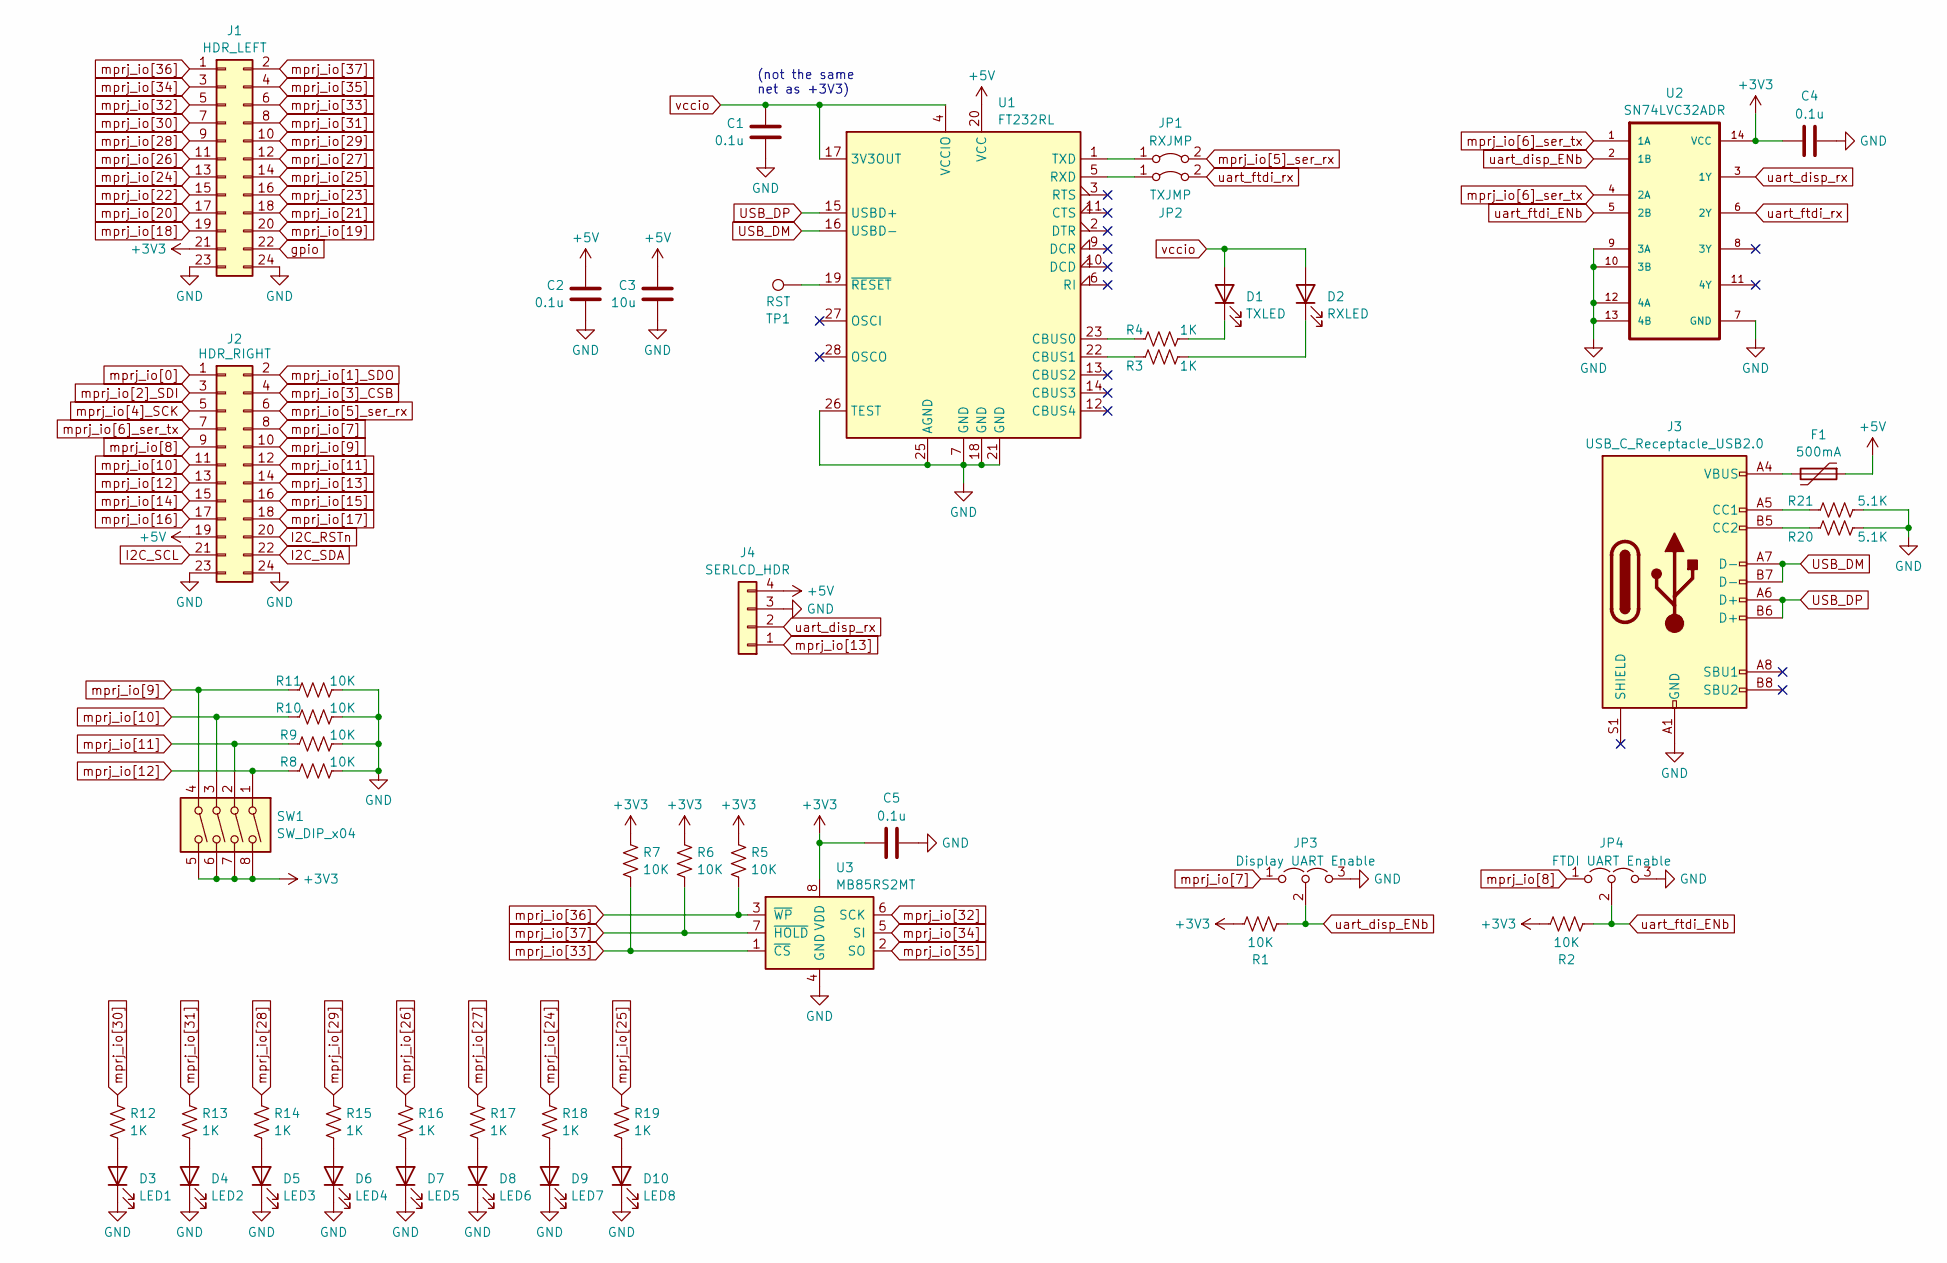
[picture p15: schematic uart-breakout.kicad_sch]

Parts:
C1, C2, C4, C5: 0.1u; C_0603_1608Metric; LCSC C14663
C3: 10u; C_0603_1608Metric; LCSC C19702
D1: TXLED; LED_0805_2012Metric; LCSC C284931
D2: RXLED; LED_0805_2012Metric; LCSC C284931
D3: LED1; LED_0805_2012Metric; LCSC C98221
D4: LED2; LED_0805_2012Metric; LCSC C98221
D5: LED3; LED_0805_2012Metric; LCSC C98221
D6: LED4; LED_0805_2012Metric; LCSC C98221
D7: LED5; LED_0805_2012Metric; LCSC C98221
D8: LED6; LED_0805_2012Metric; LCSC C98221
D9: LED7; LED_0805_2012Metric; LCSC C98221
D10: LED8; LED_0805_2012Metric; LCSC C98221
F1: 500mA; Fuse_1206_3216Metric_Pad1.42x1.75mm_HandSolder; LCSC C720075
J1: HDR_LEFT; PinHeader_2x12_P2.54mm_Vertical
J2: HDR_RIGHT; PinHeader_2x12_P2.54mm_Vertical
J3: USB_C_Receptacle_USB2.0; USB_C_Receptacle_HRO_TYPE-C-31-M-12; LCSC C5185005
J4: SERLCD_HDR; PinHeader_1x04_P2.54mm_Vertical
JP1: RXJMP; SolderJumper-2_P1.3mm_Bridged_Pad1.0x1.5mm
JP2: TXJMP; SolderJumper-2_P1.3mm_Bridged_Pad1.0x1.5mm
JP3: Display UART Enable; PinHeader_1x03_P2.54mm_Vertical
JP4: FTDI UART Enable; PinHeader_1x03_P2.54mm_Vertical
R1, R2, R5, R6, R7, R8, R9, R10, R11: 10K; R_0805_2012Metric; LCSC C17414
R3, R4, R12, R13, R14, R15, R16, R17, R18, R19: 1K; R_0805_2012Metric_Pad1.20x1.40mm_HandSolder; LCSC C17513
R20, R21: 5.1K; R_0805_2012Metric; LCSC C27834
SW1: SW_DIP_x04; SW_DIP_SPSTx04_Slide_6.7x11.72mm_W7.62mm_P2.54mm_LowProfile
TP1: RST; TestPoint_Pad_D1.5mm
U1: FT232RL; SSOP-28_5.3x10.2mm_P0.65mm; LCSC C8690
U2: SN74LVC32ADR; SOIC127P600X175-14N; LCSC C7852
U3: MB85RS2MT; SOIC-8_3.9x4.9mm_P1.27mm; LCSC C189908

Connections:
+3V3: C4.2, C5.2, J1.21, R1.2, R2.2, R5.1, R6.1, R7.1, SW1.5, SW1.6, SW1.7, SW1.8, U2.14 (VCC), U3.8 (VDD)
+5V: C2.1, C3.1, F1.1, J2.19, J4.4, U1.20 (VCC)
GND: C1.2, C2.2, C3.2, C4.1, C5.1, D3.1 (K), D4.1 (K), D5.1 (K), D6.1 (K), D7.1 (K), D8.1 (K), D9.1 (K), D10.1 (K), J1.23, J1.24, J2.23, J2.24, J3.A1 (GND), J3.A12 (GND), J3.B1 (GND), J3.B12 (GND), J4.3, JP3.3 (B), JP4.3 (B), R8.2, R9.2, R10.2, R11.2, R20.1, R21.1, U1.7 (GND), U1.18 (GND), U1.21 (GND), U1.25 (AGND), U1.26 (TEST), U2.7 (GND), U2.9 (3A), U2.10 (3B), U2.12 (4A), U2.13 (4B), U3.4 (GND)
I2C_RSTn: J2.20
I2C_SCL: J2.21
I2C_SDA: J2.22
unnamed: D1.1 (K), R4.2
unnamed: D2.1 (K), R3.1
unnamed: D3.2 (A), R12.2
unnamed: D4.2 (A), R13.2
unnamed: D5.2 (A), R14.2
unnamed: D6.2 (A), R15.2
unnamed: D7.2 (A), R16.2
unnamed: D8.2 (A), R17.2
unnamed: D9.2 (A), R18.2
unnamed: D10.2 (A), R19.2
unnamed: F1.2, J3.A4 (VBUS), J3.A9 (VBUS), J3.B4 (VBUS), J3.B9 (VBUS)
unnamed: J3.A5 (CC1), R21.2
unnamed: J3.B5 (CC2), R20.2
unnamed: JP1.1 (A), U1.1 (TXD)
unnamed: JP2.1 (A), U1.5 (RXD)
unnamed: R4.1, U1.23 (CBUS0)
unnamed: R3.2, U1.22 (CBUS1)
unnamed: TP1.1, U1.19 (~RESET)
USB_DM: J3.A7 (D-), J3.B7 (D-), U1.16 (USBD-)
USB_DP: J3.A6 (D+), J3.B6 (D+), U1.15 (USBD+)
gpio: J1.22
mprj_io[0]: J2.1
mprj_io[1]_SDO: J2.2
mprj_io[2]_SDI: J2.3
mprj_io[3]_CSB: J2.4
mprj_io[4]_SCK: J2.5
mprj_io[5]_ser_rx: J2.6, JP1.2 (B)
mprj_io[6]_ser_tx: J2.7, U2.1 (1A), U2.4 (2A)
mprj_io[7]: J2.8, JP3.1 (A)
mprj_io[8]: J2.9, JP4.1 (A)
mprj_io[9]: J2.10, R11.1, SW1.4
mprj_io[10]: J2.11, R10.1, SW1.3
mprj_io[11]: J2.12, R9.1, SW1.2
mprj_io[12]: J2.13, R8.1, SW1.1
mprj_io[13]: J2.14, J4.1
mprj_io[14]: J2.15
mprj_io[15]: J2.16
mprj_io[16]: J2.17
mprj_io[17]: J2.18
mprj_io[18]: J1.19
mprj_io[19]: J1.20
mprj_io[20]: J1.17
mprj_io[21]: J1.18
mprj_io[22]: J1.15
mprj_io[23]: J1.16
mprj_io[24]: J1.13, R18.1
mprj_io[25]: J1.14, R19.1
mprj_io[26]: J1.11, R16.1
mprj_io[27]: J1.12, R17.1
mprj_io[28]: J1.9, R14.1
mprj_io[29]: J1.10, R15.1
mprj_io[30]: J1.7, R12.1
mprj_io[31]: J1.8, R13.1
mprj_io[32]: J1.5, U3.6 (SCK)
mprj_io[33]: J1.6, R7.2, U3.1 (~CS)
mprj_io[34]: J1.3, U3.5 (SI)
mprj_io[35]: J1.4, U3.2 (SO)
mprj_io[36]: J1.1, R5.2, U3.3 (~WP)
mprj_io[37]: J1.2, R6.2, U3.7 (~HOLD)
uart_disp_ENb: JP3.2 (C), R1.1, U2.2 (1B)
uart_disp_rx: J4.2, U2.3 (1Y)
uart_ftdi_ENb: JP4.2 (C), R2.1, U2.5 (2B)
uart_ftdi_rx: JP2.2 (B), U2.6 (2Y)
vccio: C1.1, D1.2 (A), D2.2 (A), U1.4 (VCCIO), U1.17 (3V3OUT)

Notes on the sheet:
(not the same net as +3V3)

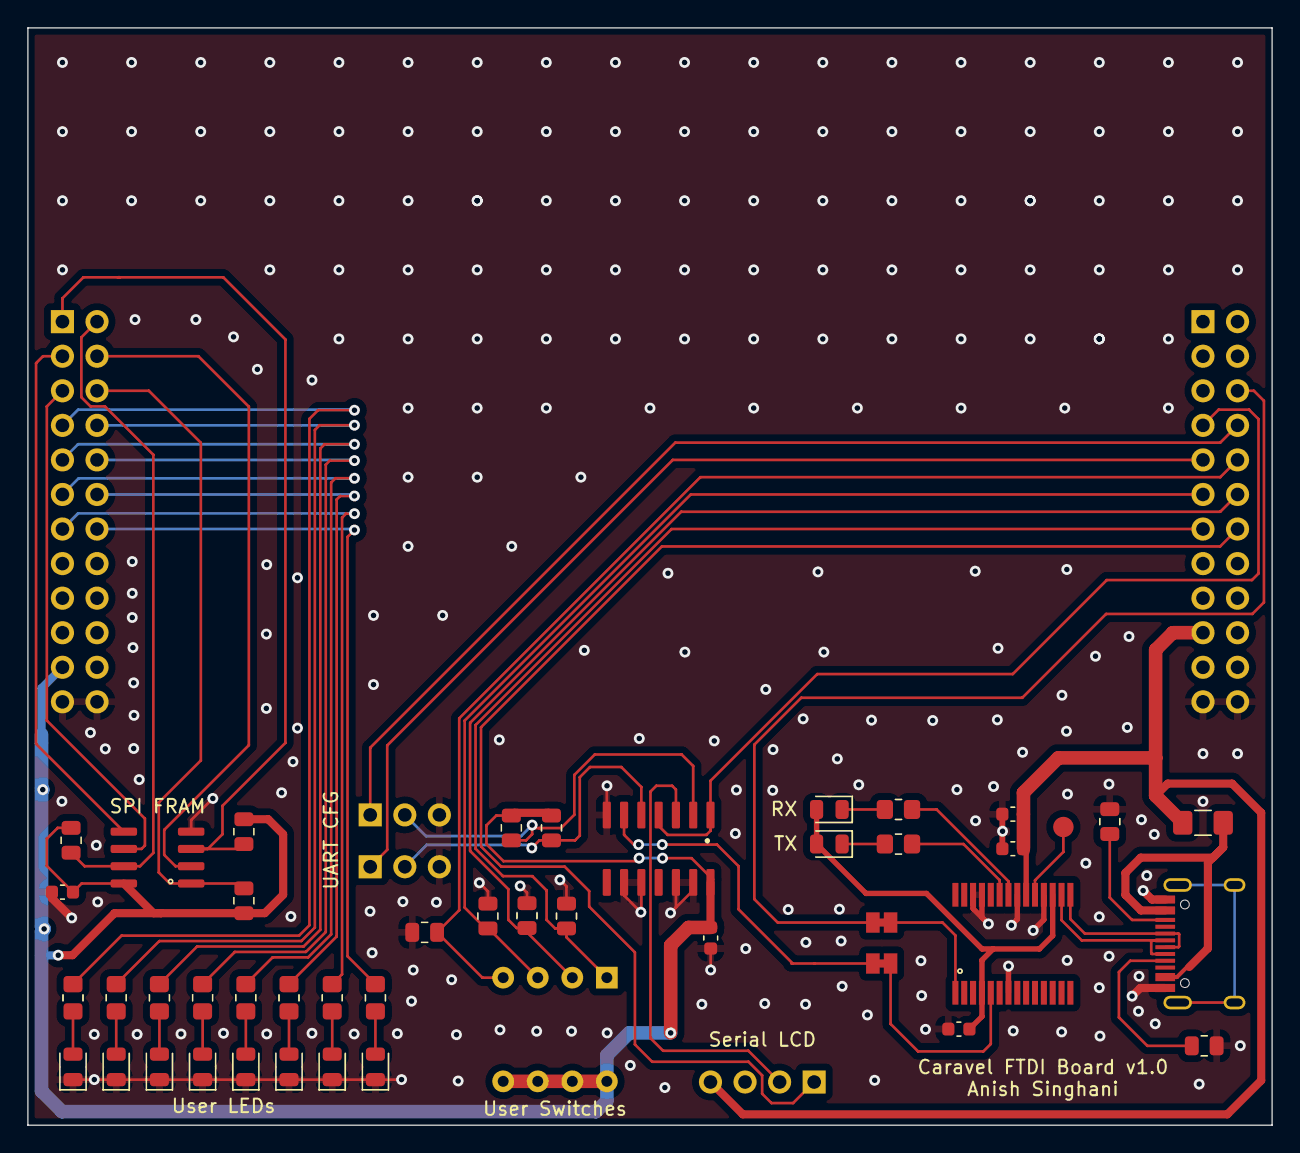
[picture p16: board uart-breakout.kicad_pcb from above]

Board: 2 copper layers, 91.4 x 80.6 mm, 50 parts (0 on the bottom side), 51 nets.

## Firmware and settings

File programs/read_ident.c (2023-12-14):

#include "../defs.h"
#include "../gpio_config/gpio_config_io.c"

// --------------------------------------------------------
// Firmware routines
// --------------------------------------------------------

void set_registers();
void printstr(char *str);
void printhex(uint32_t x, bool newline);
void printchr(char x);


uint32_t get_prog(uint32_t pc);

void setup_test() {
    reg_gpio_mode1 = 1;
    reg_gpio_mode0 = 0;
    reg_gpio_ien = 1;
    reg_gpio_oe = 1;

    //reg_uart_clkdiv = 10417;
    reg_uart_enable = 1;

    reg_mprj_xfer = 1;

    set_registers();
    reg_mprj_datah = 0;
    reg_mprj_datal = 0;
    gpio_config_io();

    reg_gpio_out = 1; // OFF

    reg_wb_enable = 1;
}

void main()
{
    setup_test();
    printstr("hello\n");

   	// Configure LA[63:0] as core -> caravel
	// Configure LA[127:64] as caravel -> core
	reg_la0_oenb = reg_la0_iena = 0x00000000;    // [31:0]
	reg_la1_oenb = reg_la1_iena = 0x00000000;    // [63:32]
	reg_la2_oenb = reg_la2_iena = 0xffffffff;    // [95:64]
	reg_la3_oenb = reg_la3_iena = 0xffffffff;    // [127:96] 

    // First test - small data
    printstr("gmorn\n");

	// SHA256 ident
	for (int i = 0; i < 64; i++) {
		reg_uart_data=(*(char*)(0x30010050+i));
		while(reg_uart_txfull==1);
		delay(50000);
	}

	// AES ident
	for (int i = 0; i < 64; i++) {
		reg_uart_data=(*(char*)(0x30000050+i));
		while(reg_uart_txfull==1);
		delay(50000);
	}
}

void printstr(char *str) {
    while (*str) printchr(*str++);
}

void printhex(uint32_t x, bool newline) {
    char *s = "0123456789abcdef";

    for (int i = 0; i < 8; i++) {
        printchr(s[(x & 0xF0000000) >> 28]);
        x = x << 4;
    }
    if(newline) printchr('\n');
}

void printchr(char x) {
    while(reg_uart_txfull==1);
    reg_uart_data=x;
    while(reg_uart_txfull==1);
}

void set_registers() {

    reg_mprj_io_0 = GPIO_MODE_MGMT_STD_INPUT_NOPULL;
    reg_mprj_io_1 = GPIO_MODE_MGMT_STD_INPUT_NOPULL;
    reg_mprj_io_2 = GPIO_MODE_MGMT_STD_INPUT_NOPULL;
    reg_mprj_io_3 = GPIO_MODE_MGMT_STD_INPUT_NOPULL;
    reg_mprj_io_4 = GPIO_MODE_MGMT_STD_INPUT_NOPULL;
    reg_mprj_io_5 = GPIO_MODE_MGMT_STD_INPUT_NOPULL;
    reg_mprj_io_6 = GPIO_MODE_MGMT_STD_OUTPUT;
    reg_mprj_io_7 = GPIO_MODE_MGMT_STD_INPUT_NOPULL;
    reg_mprj_io_8 = GPIO_MODE_MGMT_STD_INPUT_NOPULL;
    reg_mprj_io_9 = GPIO_MODE_MGMT_STD_INPUT_NOPULL;
    reg_mprj_io_10 = GPIO_MODE_MGMT_STD_INPUT_NOPULL;
    reg_mprj_io_11 = GPIO_MODE_MGMT_STD_INPUT_NOPULL;
    reg_mprj_io_12 = GPIO_MODE_MGMT_STD_INPUT_NOPULL;
    reg_mprj_io_13 = GPIO_MODE_MGMT_STD_INPUT_NOPULL;
    reg_mprj_io_14 = GPIO_MODE_MGMT_STD_INPUT_NOPULL;
    reg_mprj_io_15 = GPIO_MODE_MGMT_STD_INPUT_NOPULL;
    reg_mprj_io_16 = GPIO_MODE_MGMT_STD_INPUT_NOPULL;
    reg_mprj_io_17 = GPIO_MODE_MGMT_STD_INPUT_NOPULL;
    reg_mprj_io_18 = GPIO_MODE_MGMT_STD_INPUT_NOPULL;

    reg_mprj_io_19 = GPIO_MODE_MGMT_STD_INPUT_NOPULL;
    reg_mprj_io_20 = GPIO_MODE_MGMT_STD_INPUT_NOPULL;
    reg_mprj_io_21 = GPIO_MODE_MGMT_STD_INPUT_NOPULL;
    reg_mprj_io_22 = GPIO_MODE_MGMT_STD_INPUT_NOPULL;
    reg_mprj_io_23 = GPIO_MODE_MGMT_STD_INPUT_NOPULL;
    reg_mprj_io_24 = GPIO_MODE_MGMT_STD_INPUT_NOPULL;
    reg_mprj_io_25 = GPIO_MODE_MGMT_STD_INPUT_NOPULL;
    reg_mprj_io_26 = GPIO_MODE_MGMT_STD_INPUT_NOPULL;
    reg_mprj_io_27 = GPIO_MODE_MGMT_STD_INPUT_NOPULL;
    reg_mprj_io_28 = GPIO_MODE_MGMT_STD_INPUT_NOPULL;
    reg_mprj_io_29 = GPIO_MODE_MGMT_STD_INPUT_NOPULL;
    reg_mprj_io_30 = GPIO_MODE_MGMT_STD_INPUT_NOPULL;
    reg_mprj_io_31 = GPIO_MODE_MGMT_STD_INPUT_NOPULL;
    reg_mprj_io_32 = GPIO_MODE_MGMT_STD_INPUT_NOPULL;
    reg_mprj_io_33 = GPIO_MODE_MGMT_STD_INPUT_NOPULL;
    reg_mprj_io_34 = GPIO_MODE_MGMT_STD_INPUT_NOPULL;
    reg_mprj_io_35 = GPIO_MODE_MGMT_STD_INPUT_NOPULL;
    reg_mprj_io_36 = GPIO_MODE_MGMT_STD_INPUT_NOPULL;
    reg_mprj_io_37 = GPIO_MODE_MGMT_STD_INPUT_NOPULL;

}

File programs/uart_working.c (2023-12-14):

#include "../defs.h"
#include "../gpio_config/gpio_config_io.c"

#define UART_EV_TX	0x1
#define UART_EV_RX	0x2

#define UART_RXTX    (*(volatile uint32_t*) 0xf0005800)
#define UART_TXFULL  (*(volatile uint32_t*) 0xf0005804)
#define UART_RXEMPTY (*(volatile uint32_t*) 0xf0005808)
#define UART_EV_PEND (*(volatile uint32_t*) 0xf0005810)

void putchar(char x) {
    // Wait until ready
    while(UART_TXFULL);
    
    // Write character
    UART_RXTX = x;

    // Wait until send completed
    while(UART_TXFULL);
}

bool haschar() {
    return !UART_RXEMPTY;
}

char getchar() {
    while (!haschar());

    // Read the data
    uint8_t c = UART_RXTX;
    
    // Clear the data out of the FIFO
    UART_EV_PEND = UART_EV_RX;

    return c;
}

void main() {
    // Enable the GPIO LED
    reg_gpio_mode1 = 1;
    reg_gpio_mode0 = 0;
    reg_gpio_ien = 1;
    reg_gpio_oe = 1;
    reg_gpio_out = 1;

    // Enable UART
    reg_uart_enable = 1;

    // Setup the I/O
    reg_mprj_xfer = 1;
    reg_mprj_io_5 = GPIO_MODE_MGMT_STD_INPUT_NOPULL;
    reg_mprj_io_6 = GPIO_MODE_MGMT_STD_OUTPUT;
    reg_mprj_datah = 0;
    reg_mprj_datal = 0;
    gpio_config_io();

    while (true) {
        char c = getchar();
        
        // Toggle LED every time character recieved
        reg_gpio_out = !reg_gpio_out;

        // Write the recieved character + 1
        putchar(c+1);
    }
}
